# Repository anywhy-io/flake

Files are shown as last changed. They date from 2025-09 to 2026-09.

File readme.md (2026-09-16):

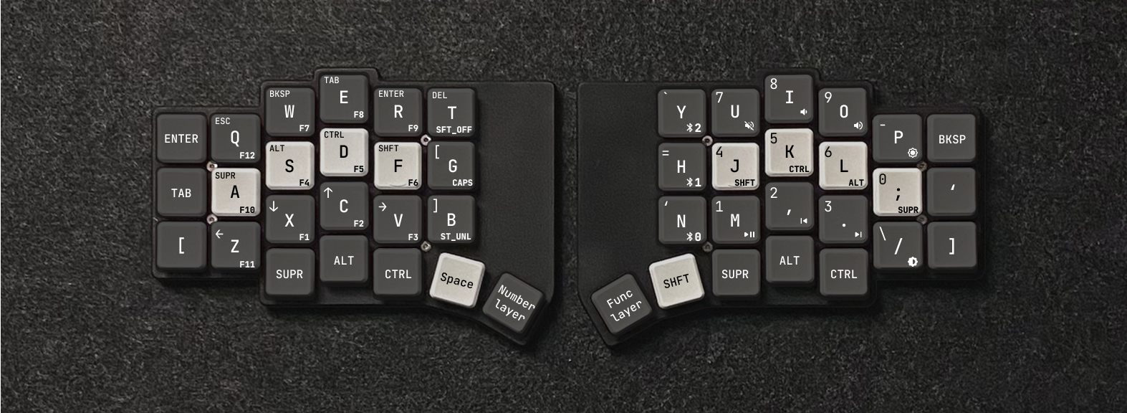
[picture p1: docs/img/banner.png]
Anywhy Flake keyboard


**Anywhy Flake**

_An open, programmable, wireless, ergonomic keyboard_

## Features

- All docs and design files are public. Parts are standard and replaceable.
- Three sizes: S (40 keys), M (46), or L (58).
- Hybrid hot-swap sockets fit low- and high-profile switches: MX, Choc v1, Choc v2, GLP v3.
- Remap any key. Add layers, macros, and combos.
- The case is 9 mm thick, without switches or feet.
- The two halves link over Bluetooth, and your device connects over Bluetooth or USB-C.
- A single charge gives 4 weeks on the main half and 6 months on the secondary.[^battery]

## Documentation

- [Gallery](./docs/gallery.md)
- [Manufacturing Files](./docs/manufacturing_files.md)
- [Build Guide](./docs/build_guide.md)
- [Flashing Guide](https://github.com/anywhy-io/flake-firmware/blob/main/docs/flashing_guide.md)

## License

CERN-OHL-W-2.0. See [LICENSE](./LICENSE).

[^battery]: Assumes 12 hours of continuous use per day, every day.

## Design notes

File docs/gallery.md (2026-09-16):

---
title: Gallery
---

# Anywhy Flake Gallery

Welcome to the gallery, here you will find amazing Flake builds made by people. This page will be constantly expanding, so if you have a build you want to share, feel free to contact me and I'll add it here.

## by [@Constant_Pin_7757](https://www.reddit.com/r/ErgoMechKeyboards/comments/1q6lvwh/comment/ny8om0r/)

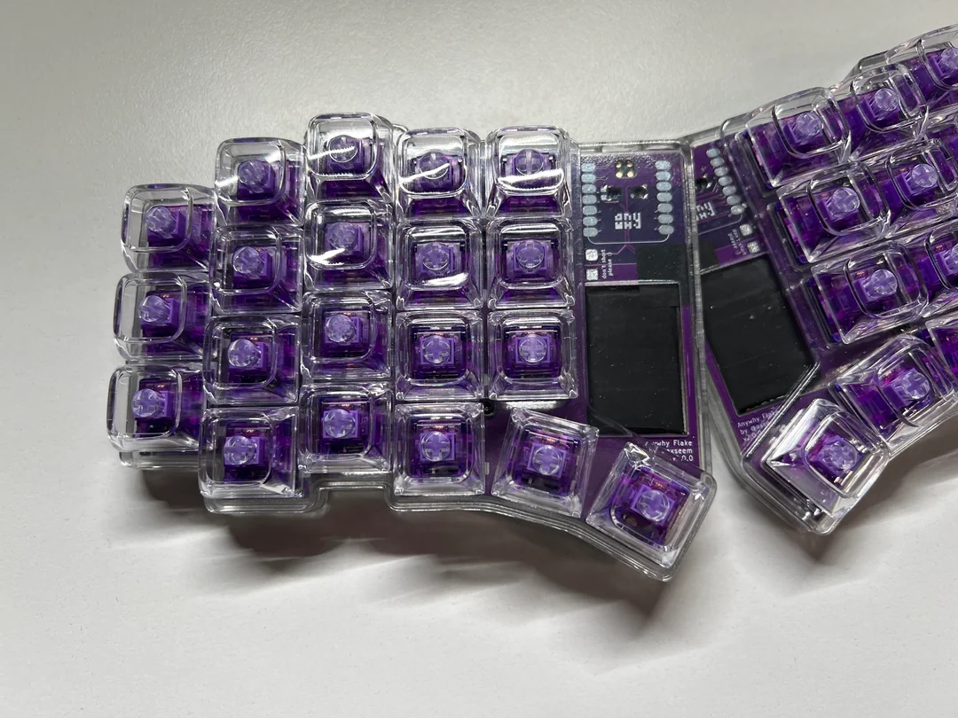
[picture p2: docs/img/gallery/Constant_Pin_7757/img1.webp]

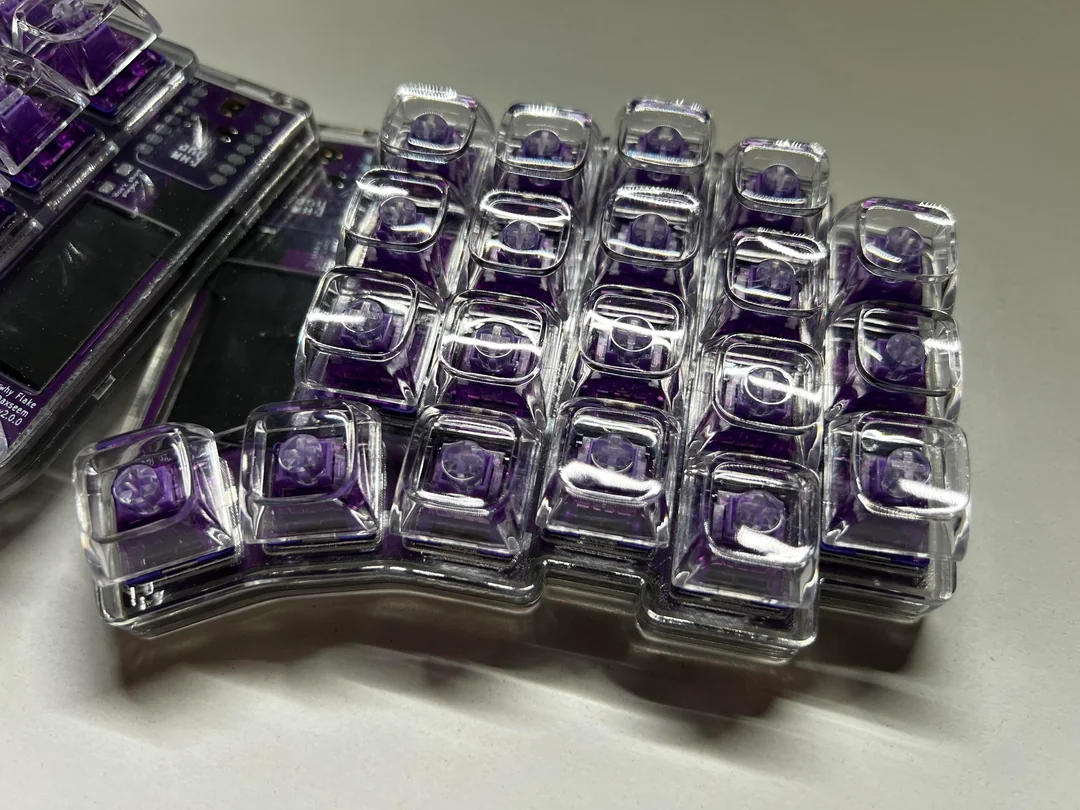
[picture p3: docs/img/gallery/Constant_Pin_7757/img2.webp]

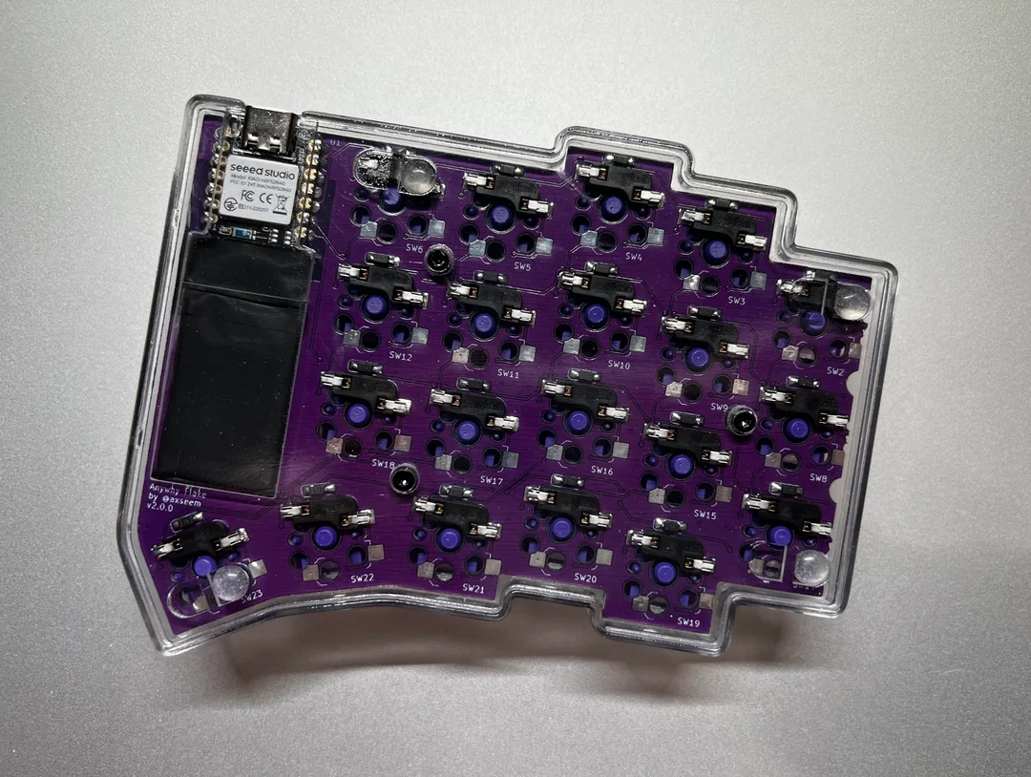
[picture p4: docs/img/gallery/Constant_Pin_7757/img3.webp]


Flake S with transparent housing, lavender PCB and MX switches

## by [@peppapighs](https://www.reddit.com/r/ErgoMechKeyboards/comments/1jbw0kt/my_custom_flake/)

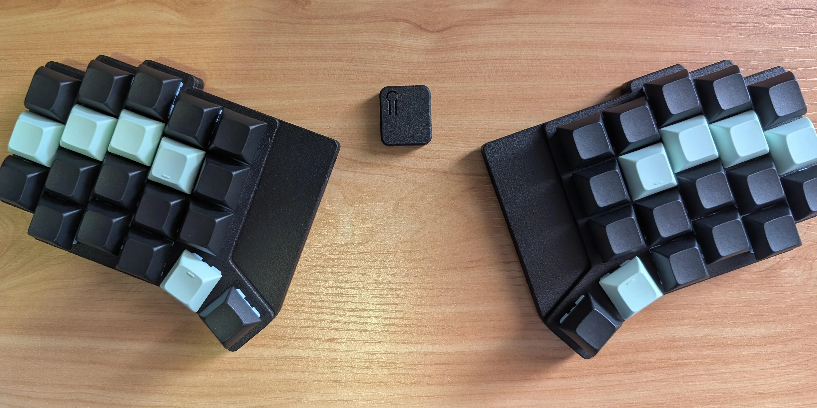
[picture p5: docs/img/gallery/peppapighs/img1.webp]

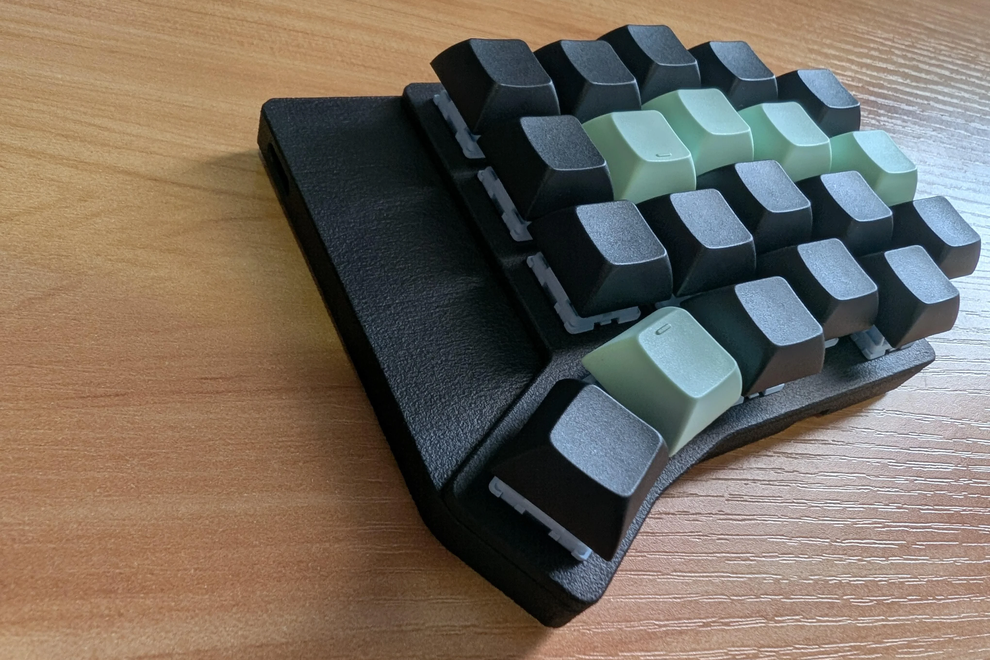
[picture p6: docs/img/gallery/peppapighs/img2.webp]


Flake S with modified PCB adding through-holes for MCU mounting

## by [@caiodelgado](https://www.reddit.com/r/ErgoMechKeyboards/comments/1iz07kw/anywhy_flake_choc_v1_robinsunset_tenting/)

Flake with Choc v1 Robin switches, 3d-printed keycaps and tenting legs

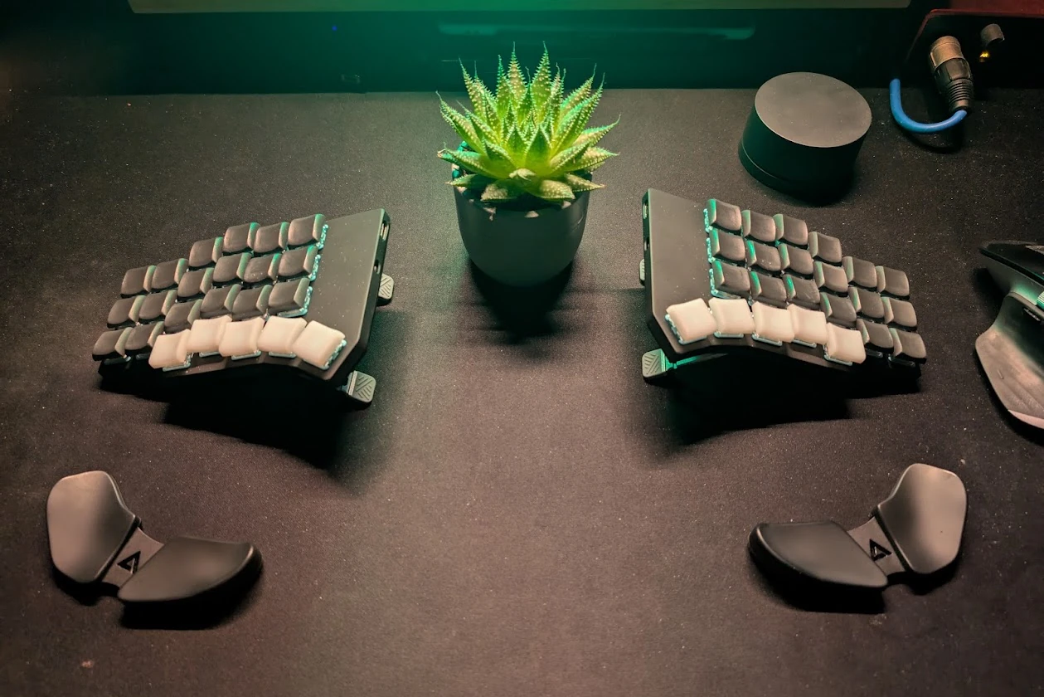
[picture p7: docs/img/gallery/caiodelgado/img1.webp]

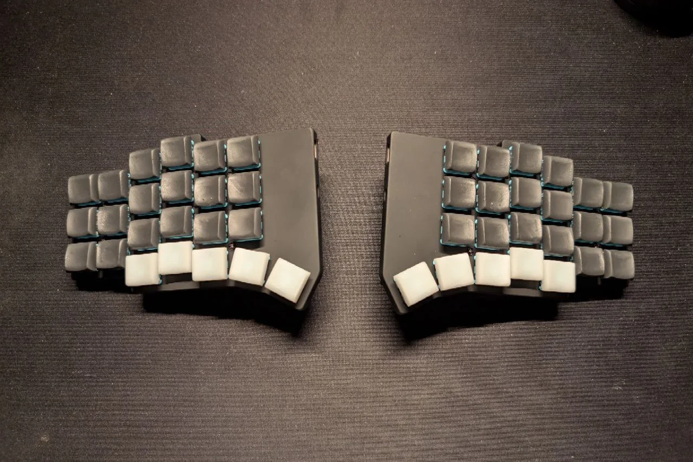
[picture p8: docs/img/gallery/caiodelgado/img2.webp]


## by [@kurisutofujp](https://www.reddit.com/r/ErgoMechKeyboards/comments/1iirgyt/comment/mb9034h/)

Snow-white Flake L with MX switches

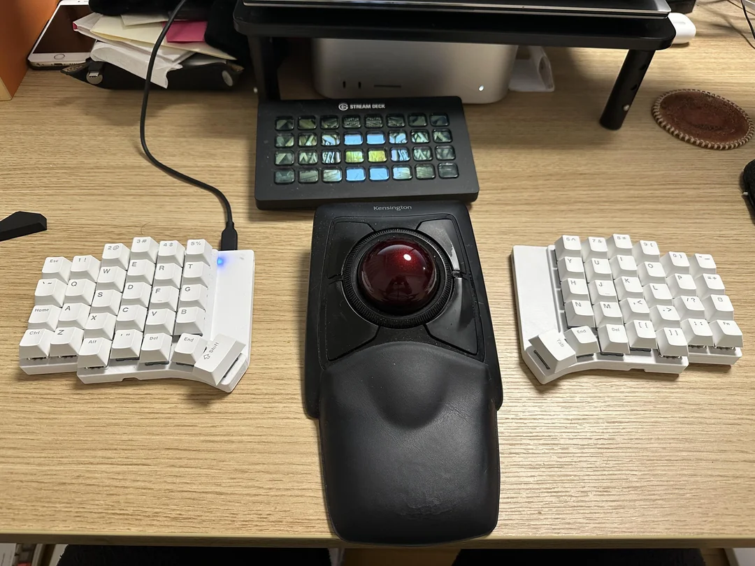
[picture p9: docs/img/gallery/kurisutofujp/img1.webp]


## by [@devpew](https://www.reddit.com/r/ErgoMechKeyboards/comments/1ieevvh/flake/)

Clean white Flake M with black keycaps

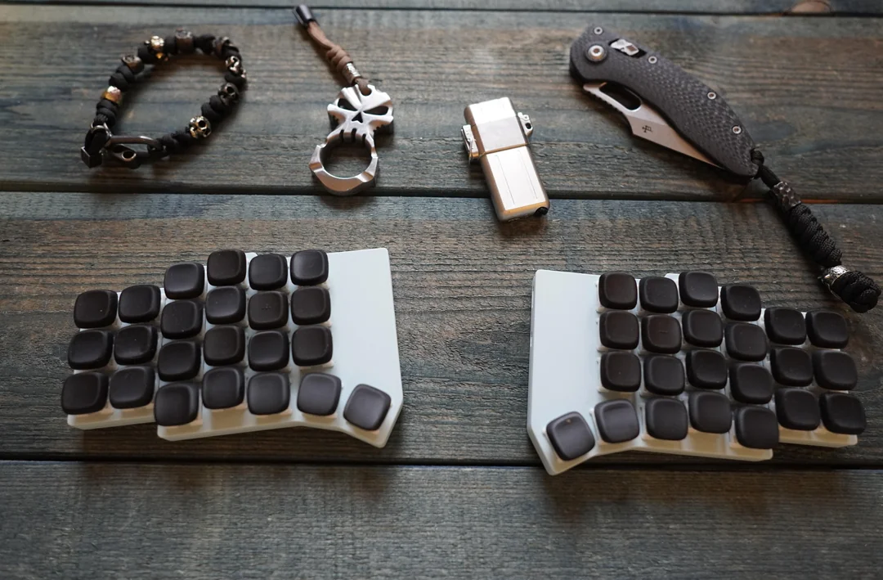
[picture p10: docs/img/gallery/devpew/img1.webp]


## by [@CaptLynx](https://www.reddit.com/r/ErgoMechKeyboards/comments/1ic3nkc/caitlynarcane_themed_anywhy_flake/)

The design is inspired by Caitlyn, a character from the Arcane series.

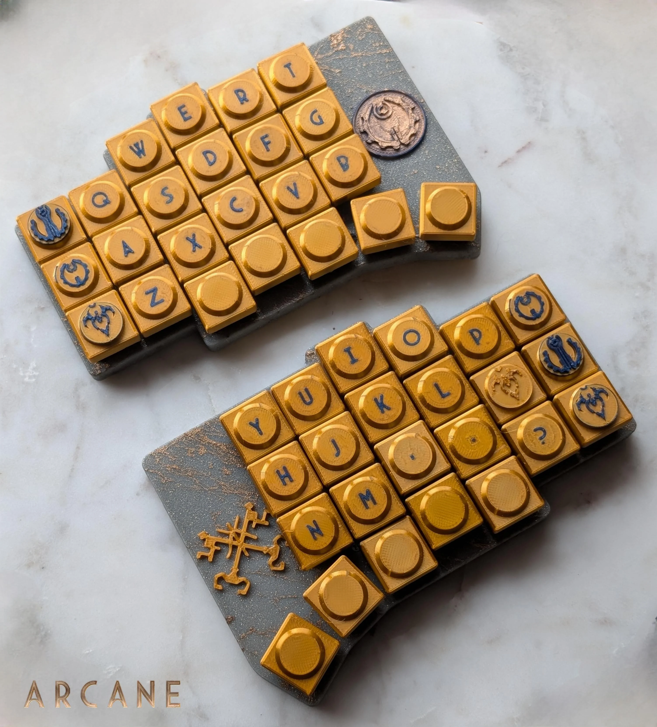
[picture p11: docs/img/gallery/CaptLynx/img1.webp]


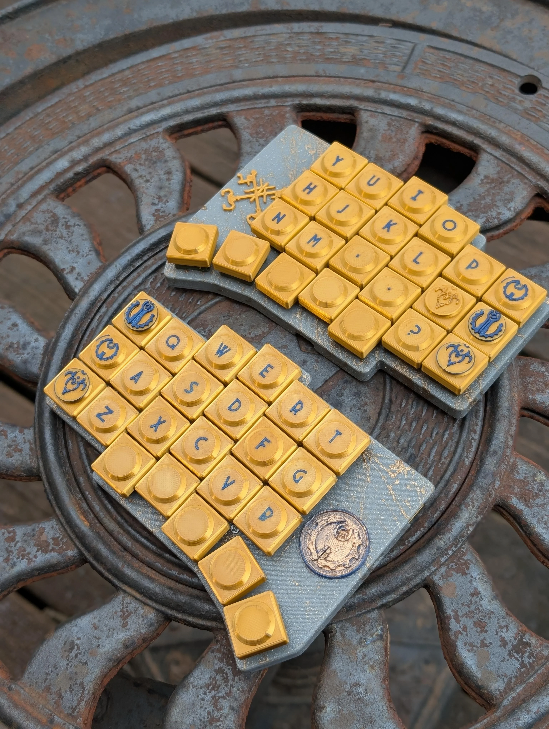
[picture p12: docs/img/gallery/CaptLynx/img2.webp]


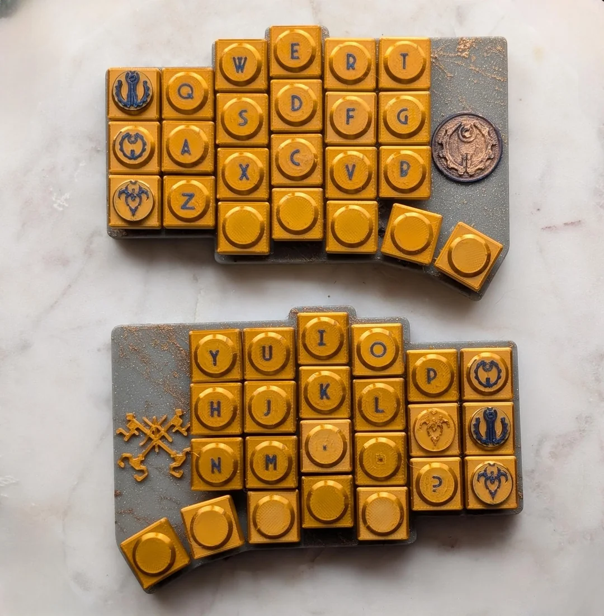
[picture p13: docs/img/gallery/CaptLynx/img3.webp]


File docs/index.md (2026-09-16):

---
title: Flake
---

Flake Keyboard

## Anywhy Flake

*An open-source, wireless, split ergonomic keyboard designed to be productive, healthy, and enjoyable.*

## Why Flake?

By the 19th century, a need for a faster way of writing had emerged, leading to the invention of typewriters. Two centuries later, modern keyboards don't look much different, even though their monolithic, row-staggered design has been proven to be inefficient and often harmful.

The Flake keyboard addresses these problems from the ground up, providing huge benefits in comfort and efficiency for anyone who spends their day typing.

## Core Features

*   **Split Ergonomic Design:** Place each half where it feels best, eliminating wrist strain.
*   **Columnar Stagger:** Keys are arranged to follow the natural movement of your fingers.
*   **Wireless First:** True wireless freedom with Bluetooth LE. At least 4 weeks of battery on the main half and 6 months on the secondary.[^battery]
*   **Hybrid Hot-Swap:** Supports **MX**, **Kailh Choc v1**, **Kailh Choc v2** and **GLP v3** switches.
*   **Three Sizes:** Choose the layout that fits you perfectly: **Small (40)**, **Medium (46)**, or **Large (58)** keys.
*   **Ultra-Thin Profile:** An incredibly sleek and low-profile body for maximum comfort.
*   **Fully Open:** All hardware and software files are published. Standard replaceable parts, no lock-in, no cloud — it's yours to build, modify, and repair.

## The Philosophy Behind the Design

### Split Layout
Regular keyboards force your forearms to converge, bending your wrists at an unnatural angle that can lead to long-term pain. A split keyboard allows you to position each half independently, aligning your hands, wrists, and forearms in a straight, comfortable line. As a bonus, you get free space between the halves for a trackpad, notebook, or even a cat =^..^=

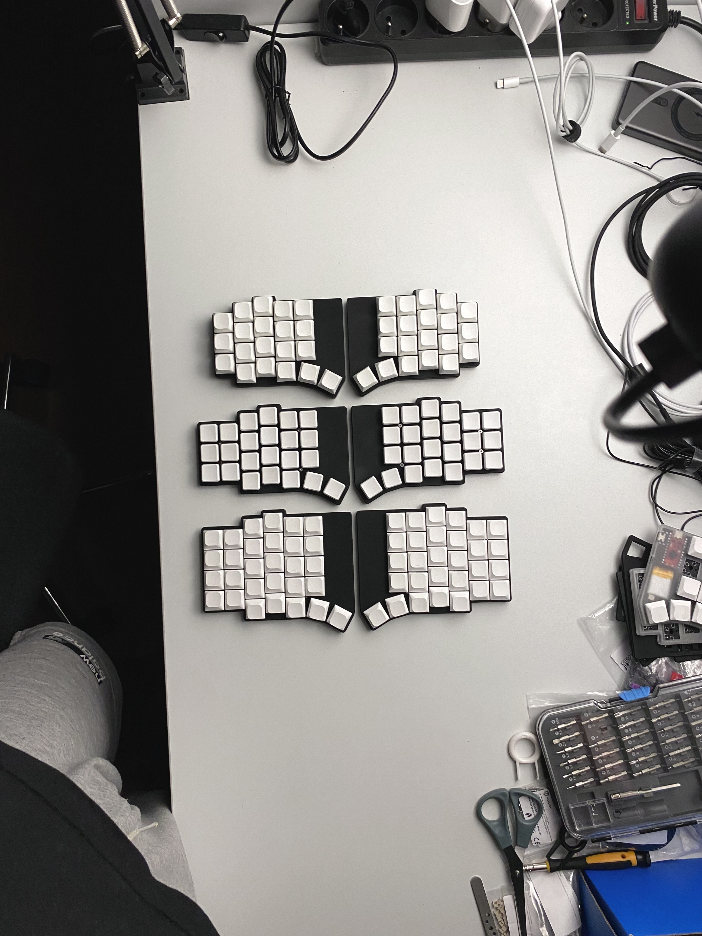
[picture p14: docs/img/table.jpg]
Ergonomic positioning of a split keyboard


### Columnar Stagger
Look at your hand - your fingers have different lengths and prefer to move up and down. Now look at a traditional keyboard - the keys are shifted horizontally. This "row stagger" forces your fingers to make awkward, unnatural movements. Flake uses a "columnar stagger", where each column is shifted vertically to match the natural reach of your fingers, resulting in a much more pleasant and efficient typing experience.

row-based stagger keyboard image

Comparison of row stagger and column stagger

### Hybrid Switch Support
The world of mechanical switches is vast and exciting, but choosing just one type can be limiting. Flake solves this with hybrid hot-swap sockets. Each key position has sockets for both **Cherry MX-style** and **low-profile Kailh Choc** switches. This gives you the freedom to experiment with different switch types at any time.

To provide the best typing feel and stability for the taller MX switches, a dedicated switch plate is included with the case files. This plate is placed over the PCB before inserting the switches, ensuring they are held securely. Low-profile Choc switches mount directly and do not require the plate.

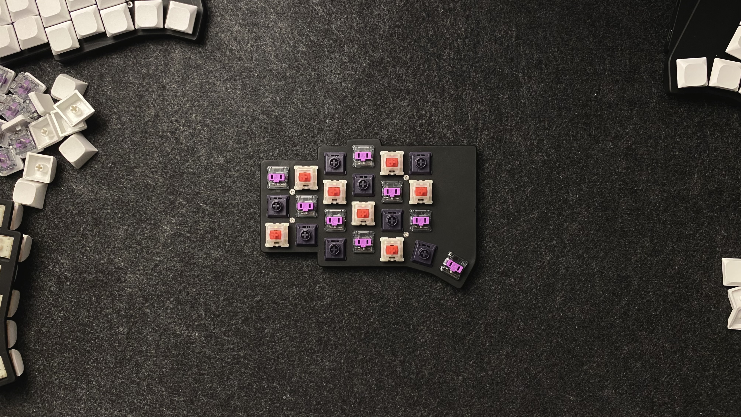
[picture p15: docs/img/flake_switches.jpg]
Flake keyboard showing both MX and Choc switches


### Fewer Keys, More Power
A small key count might seem counterintuitive for productivity, but it's a core feature, not a compromise. Fewer keys mean your hands stay in one place, eliminating the need to stretch for distant keys.

This doesn't mean less functionality. Powered by the incredible [ZMK Firmware](https://zmk.dev), Flake uses [layers](https://zmk.dev/docs/keymaps#layers) to access every key a traditional keyboard has and more. You can have dedicated layers for numbers, symbols, navigation, macros, and anything else you can imagine, all just a thumb press away.

Visual representation of keyboard layers in ZMK

To accommodate different preferences, Flake comes in three sizes:
*   **Flake L (58 keys):** For those who prefer more dedicated keys.
*   **Flake M (46 keys):** A perfect balance of function and form.
*   **Flake S (40 keys):** For the ultimate in minimalism and ergonomics.

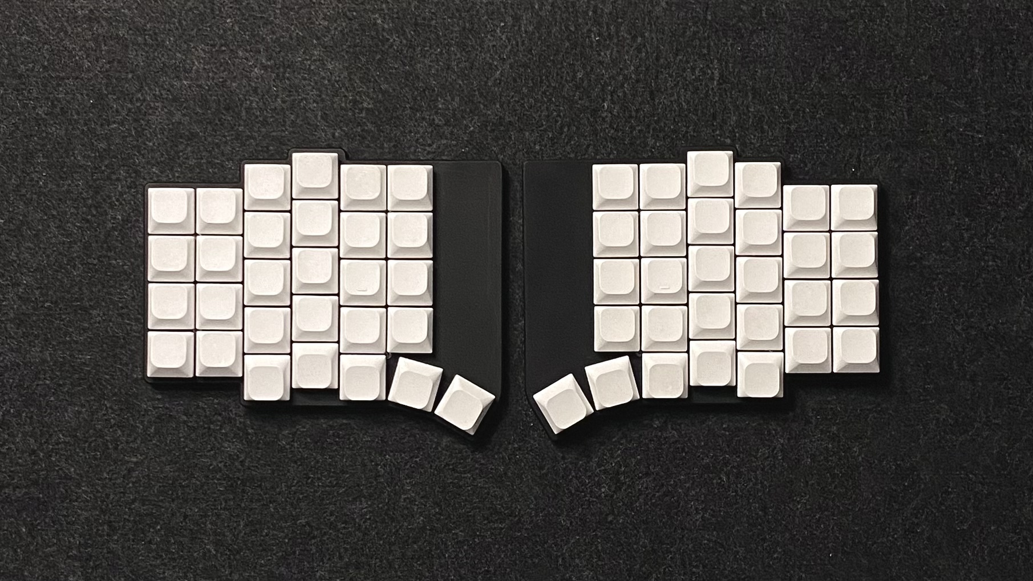
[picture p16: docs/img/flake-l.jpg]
Flake L keyboard


### Ultra-Thin Profile
The keyboard body is only **~9mm** thick (without feet). Combined with low-profile Choc switches and keycaps, this creates an extremely low-to-the-desk typing experience, further reducing wrist strain.

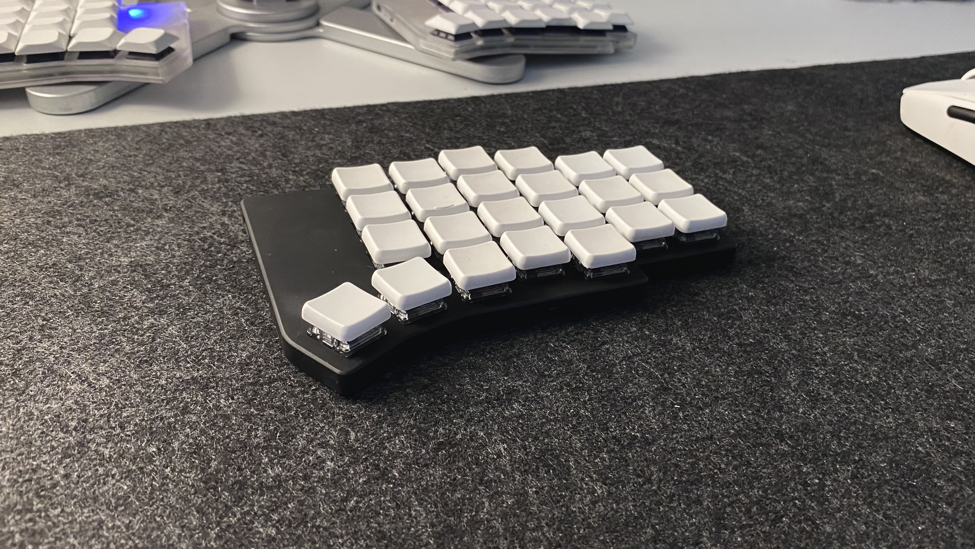
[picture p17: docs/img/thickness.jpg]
Side profile showing the thinness of the Flake keyboard


## Build Your Own Flake

Ready to build one? The comprehensive build guide has everything you need to get started.
➡️ **[Read the Official Build Guide](./build_guide.md)**

Also, be sure to check out the gallery to see amazing builds from the community!
➡️ **[Explore the Gallery ✨](./gallery.md)**

Firmware installation and keymap customization are covered in the firmware documentation.
➡️ **[Flashing Guide](https://github.com/anywhy-io/flake-firmware/blob/main/docs/flashing_guide.md)**

## Credits

Huge thanks to:
-   [@foostan](https://github.com/foostan) for the [Corne Keyboard](https://github.com/foostan/crkbd), my introduction to the world of ergonomic keyboards.
-   [@pashutk](https://github.com/pashutk) for the [Chocofi](https://github.com/pashutk/chocofi), an amazing tiny keyboard I've been using for a while.
-   [@josefadamcik](https://github.com/josefadamcik) for the [Sofle](https://github.com/josefadamcik/SofleKeyboard), which heavily inspired the Flake's key layout.
-   [@carrefinho](https://github.com/carrefinho) for the [Forager](https://github.com/carrefinho/forager). Its clever controller mount allowed v2 to use the Seeed Xiao controller while keeping the keyboard thin.
-   [@ebastler](https://github.com/ebastler/) for his amazing [marbastlib](https://github.com/ebastler/marbastlib), which is used as the basis for the switch footprints.
-   [@petejohanson](https://github.com/petejohanson) and all the [contributors](https://github.com/zmkfirmware/zmk/graphs/contributors) for creating and maintaining the incredible [ZMK Firmware](https://github.com/zmkfirmware/zmk).
-   Everyone working on [KiCad](https://gitlab.com/kicad/code/kicad) and [FreeCAD](https://github.com/FreeCAD/FreeCAD) for creating such powerful open source tools.
-   The helpful and kind people from the [ZMK Discord server](https://zmk.dev/community/discord/invite) who helped me learn PCB design and solve countless problems.
-   Thank you to everyone who explores unpopular technologies, digs into niche topics, and makes amazing things possible.

[^battery]: Assumes 12 hours of continuous use per day, every day.

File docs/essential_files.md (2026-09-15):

---
title: Essential Files
---

# Where is the PCB Gerber file?

You can find these files in their respective directories based on keyboard size:

```
pcb/<keyboard-size>/production/
```

Download the appropriate Gerber files for your keyboard version:

- [Flake S/M](https://github.com/anywhy-io/flake/blob/main/pcb/M%2CS/production/Flake.zip)
- [Flake L](https://github.com/anywhy-io/flake/blob/main/pcb/L/production/Flake-L.zip)
  
# Where are the Enclosure files?

Enclosure files are organized by keyboard size in the following directory structure:

```
enclosure/<keyboard-size>/
```

Select the enclosure files matching your keyboard version:

- [Flake S](https://github.com/anywhy-io/flake/tree/main/enclosure/S)
- [Flake M](https://github.com/anywhy-io/flake/tree/main/enclosure/M)
- [Flake L](https://github.com/anywhy-io/flake/tree/main/enclosure/L)

There you can also find a variant of back plate with cutout for battery connector.

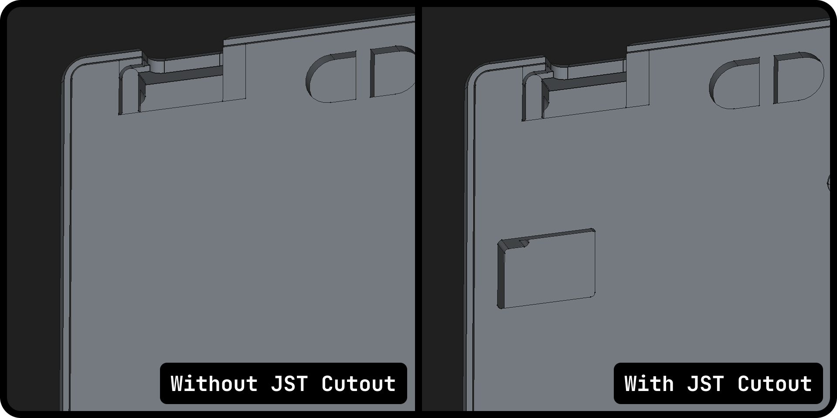
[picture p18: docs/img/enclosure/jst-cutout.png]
ZMK Studio USB connection


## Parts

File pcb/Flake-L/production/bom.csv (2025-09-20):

Designator | Footprint | Quantity | Value | LCSC Part #
BAT+1, BAT-1 | Pad | 2 | Pad
BT1 | JST_1.25mm_Reversible | 1 | Battery
D1, D10, D11, D12, D13, D14, D15, D16, D17, D18, D19, D2, D20, D21, D22, D23, D24, D25, D26, D27, D28, D29, D3, D4, D5, D6, D7, D8, D9 | D_SOD-123_HandSoldering_Reversible | 29 | D
SW1, SW10, SW11, SW12, SW13, SW14, SW15, SW16, SW17, SW18, SW19, SW2, SW20, SW21, SW22, SW23, SW24, SW25, SW26, SW27, SW28, SW29, SW3, SW4, SW5, SW6, SW7, SW8, SW9 | SW_MX_Choc_Hotswap_Reversible | 29 | SW_Push
U1 | XIAO-nRF52840-SMD | 1 | XIAO-nRF52840-SMD

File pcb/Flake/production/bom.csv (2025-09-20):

Designator | Footprint | Quantity | Value | LCSC Part #
_2, |  | 2
BAT+1, BAT-1 | Pad | 2 | Pad
BT1 | JST_1.25mm_Reversible | 1 | Battery
D1, D10, D11, D12, D13, D14, D15, D16, D17, D18, D19, D2, D20, D21, D22, D23, D3, D4, D5, D6, D7, D8, D9 | D_SOD-123_HandSoldering_Reversible | 23 | D
SW1, SW10, SW11, SW12, SW13, SW14, SW15, SW16, SW17, SW18, SW19, SW2, SW20, SW21, SW22, SW23, SW3, SW4, SW5, SW6, SW7, SW8, SW9 | SW_MX_Choc_Hotswap_Reversible | 23 | SW_Push
U1 | XIAO-nRF52840-SMD | 1 | XIAO-nRF52840-SMD

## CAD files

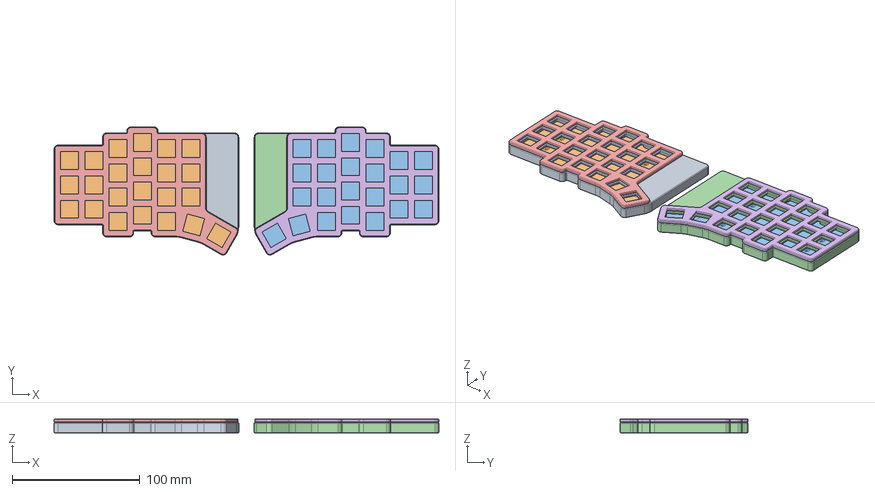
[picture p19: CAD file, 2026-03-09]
enclosure/Enclosure.FCStd
301.4 x 100.4 x 11.3 mm
Top-Left
Bottom-Left001
Bottom-Right001
Top-Right
Plate-Left
Plate-Right

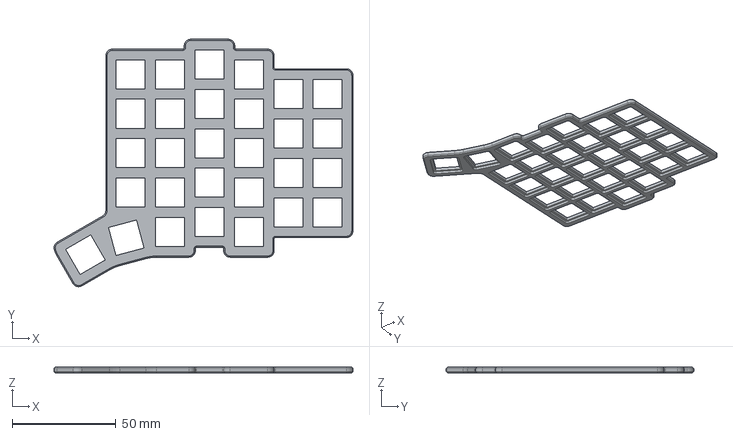
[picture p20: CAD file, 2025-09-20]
enclosure/L/Flake-L-MX-Plate-Right.step
144.2 x 119.4 x 2.80 mm

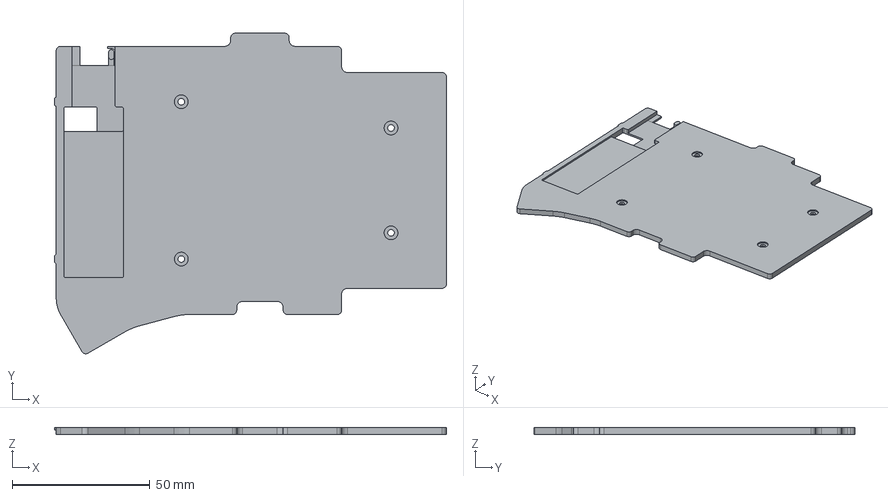
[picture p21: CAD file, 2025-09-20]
enclosure/L/with-jst-cutout/Flake-L-Bottom-Right-JST-Cutout.step
142.1 x 116.2 x 2.60 mm

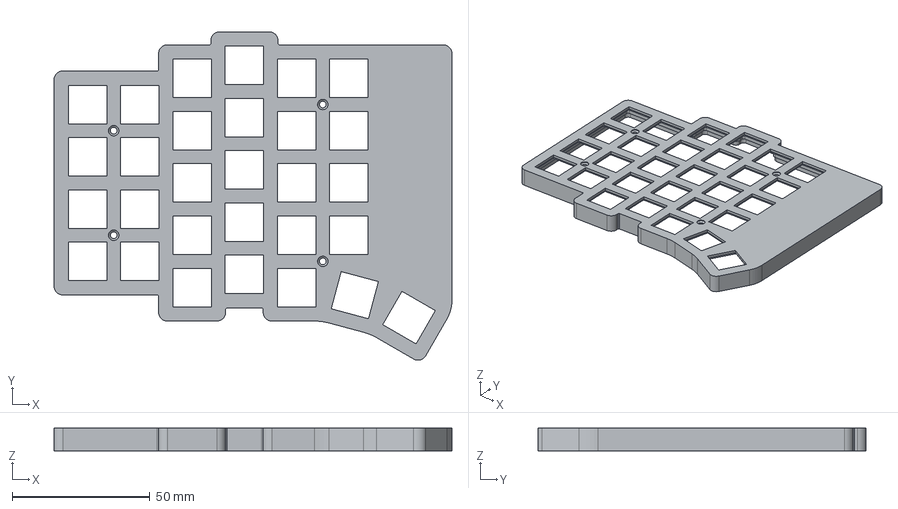
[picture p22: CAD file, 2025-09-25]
enclosure/L/without-chamfer/Flake-L-Top-Left-No-Chamfer.step
144.7 x 119.4 x 8.30 mm

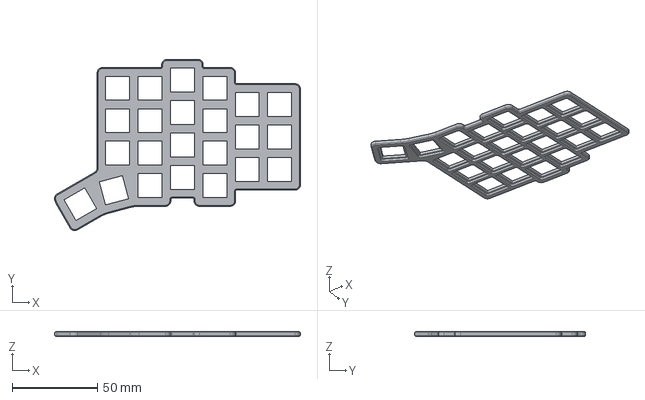
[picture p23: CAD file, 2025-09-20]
enclosure/M/Flake-M-MX-Plate-Right.step
144.2 x 100.4 x 2.80 mm

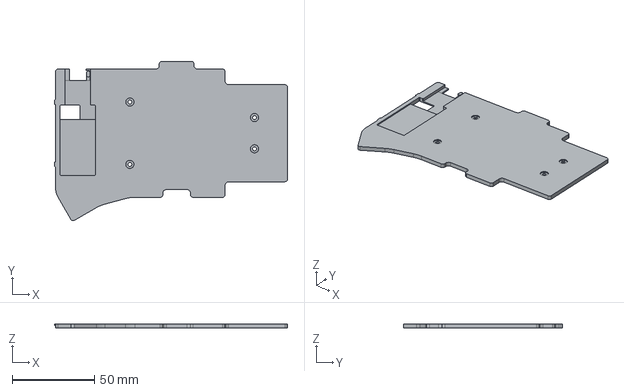
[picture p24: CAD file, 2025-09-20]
enclosure/M/with-jst-cutout/Flake-M-Bottom-Right-JST-Cutout.step
142.1 x 97.2 x 2.60 mm

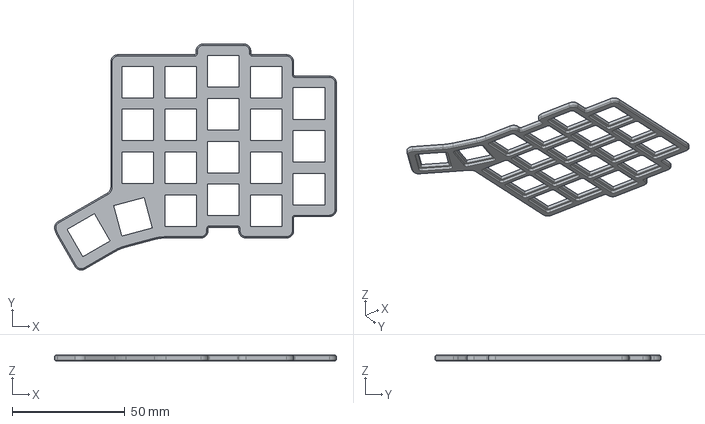
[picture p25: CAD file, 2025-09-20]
enclosure/S/Flake-S-MX-Plate-Right.step
125.2 x 100.4 x 2.80 mm

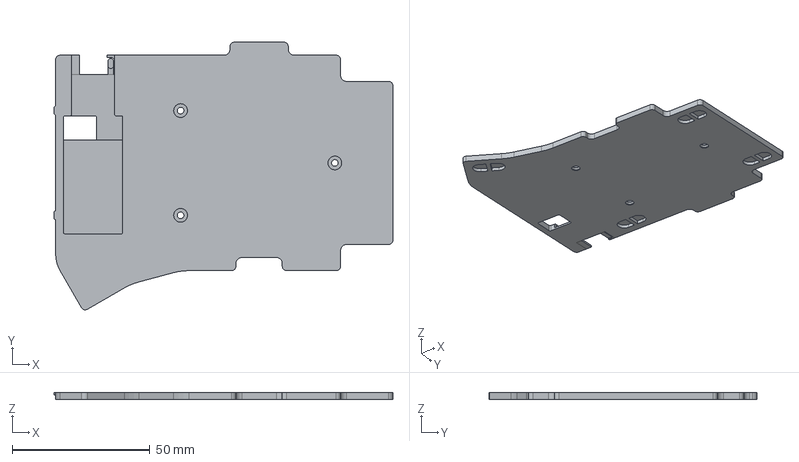
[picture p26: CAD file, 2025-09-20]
enclosure/S/with-jst-cutout/Flake-S-Bottom-Right-JST-Cutout.step
123.1 x 97.2 x 2.60 mm

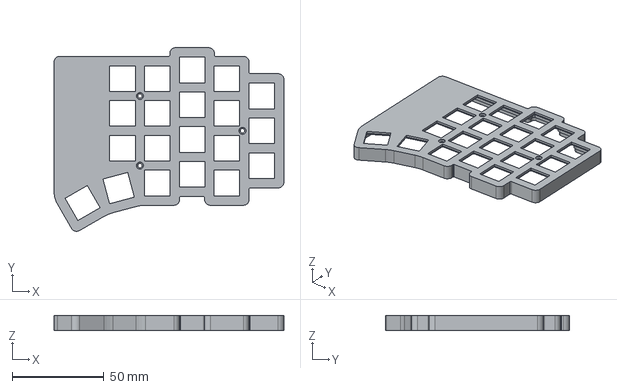
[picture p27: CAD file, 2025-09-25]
enclosure/S/without-chamfer/Flake-S-Top-Right-No-Chamfer.step
125.6 x 100.4 x 8.30 mm

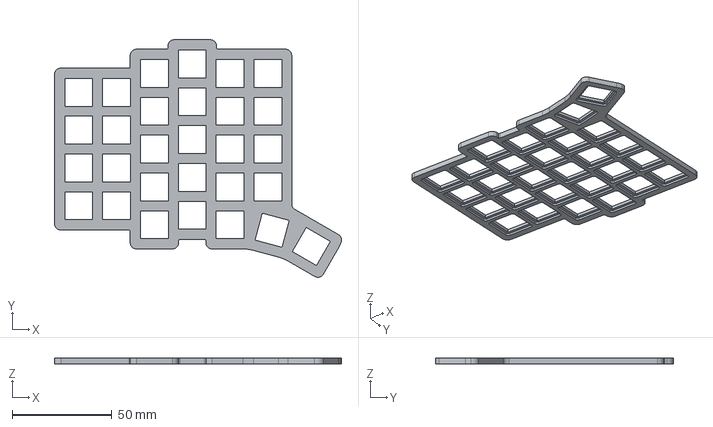
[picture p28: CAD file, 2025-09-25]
enclosure/L/without-chamfer/Flake-L-MX-Plate-Left-No-Chamfer.step
144.2 x 119.4 x 2.80 mm

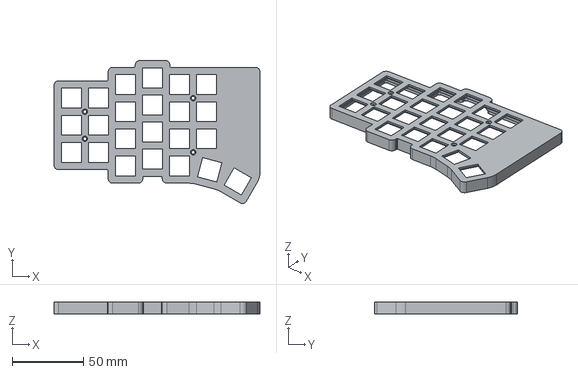
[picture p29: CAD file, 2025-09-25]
enclosure/M/without-chamfer/Flake-M-Top-Left-No-Chamfer.step
144.6 x 100.4 x 8.30 mm

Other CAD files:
enclosure/M/without-chamfer/Flake-M-MX-Plate-Left-No-Chamfer.step
enclosure/L/Flake-L-MX-Plate-Left.step
enclosure/L/with-jst-cutout/Flake-L-Bottom-Left-JST-Cutout.step
enclosure/M/Flake-M-MX-Plate-Left.step
enclosure/M/with-jst-cutout/Flake-M-Bottom-Left-JST-Cutout.step
enclosure/S/Flake-S-MX-Plate-Left.step
enclosure/S/with-jst-cutout/Flake-S-Bottom-Left-JST-Cutout.step
enclosure/L/Flake-L-Bottom-Left.step
enclosure/L/Flake-L-Bottom-Right.step
enclosure/L/Flake-L-Top-Left.step
enclosure/L/Flake-L-Top-Right.step
enclosure/L/without-chamfer/Flake-L-MX-Plate-Right-No-Chamfer.step
enclosure/L/without-chamfer/Flake-L-Top-Right-No-Chamfer.step
enclosure/M/Flake-M-Bottom-Left.step
enclosure/M/Flake-M-Bottom-Right.step
enclosure/M/Flake-M-Top-Left.step
enclosure/M/Flake-M-Top-Right.step
enclosure/M/without-chamfer/Flake-M-MX-Plate-Right-No-Chamfer.step
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

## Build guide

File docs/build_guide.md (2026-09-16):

---
title: Build Guide
---

# Flake Keyboard Build Guide

Welcome to the official build guide for the Flake keyboard! This guide is designed to be comprehensive and easy to follow, even if this is your first time building a keyboard.

I recommend reading through the entire guide once before you begin to familiarize yourself with the process.

## Prerequisites

Before you start soldering or assembling, make sure you have all the necessary components and tools.

### Required Tools

- **Soldering Iron:** A quality soldering iron with adjustable temperature control is essential.
- **Solder:** Lead-free solder is strongly recommended for health and safety.
- **Flux:** A flux pen or paste will make soldering significantly easier.
- **Tweezers:** Essential for handling small components.
- **Screwdriver:** For the M2 screws used in the case.
- **(Optional) Multimeter:** Useful for troubleshooting.

### Required Files

You will need the manufacturing files for the PCB and the enclosure. You can find all the necessary files and instructions on where to order them here:
➡️ **[Manufacturing Files and Ordering Guide](manufacturing_files.md)**

### Bill of Materials (BOM)

The required components vary based on the size of the keyboard you are building. The number of keys for each size is:

- **Small:** 40 keys
- **Medium:** 46 keys
- **Large:** 58 keys

| Component | Small (40) | Medium (46) | Large (58) | Notes |
| :---| :---: | :---: | :---: | :--- |
| **Soldering Components** | | | | |
| Anywhy Flake v2 PCB | 2 | 2 | 2 | One for each half |
| Seeed Xiao nRF52840 | 2 | 2 | 2 | The microcontroller |
| JST 1.25 SMD 2pin Horizontal Connector | 2 | 2 | 2 | For the battery |
| MX Hot-swap Sockets | 40 | 46 | 58 | See note below |
| Choc Hot-swap Sockets | 40 | 46 | 58 | See note below |
| 1N4148 Diodes | 40 | 46 | 58 | 1 per switch (SOD-123 or SOD-323) |
| **Assembly Components** | | | | |
| Soldered PCB | 2 | 2 | 2 | From the step above |
| Switches (Choc v1/v2 or MX) | 40 | 46 | 58 | 1 per socket |
| Keycaps | 40 | 46 | 58 | Must be compatible with your switches |
| Enclosure | 1 set | 1 set | 1 set | Includes top and bottom parts for each half |
| 502030 LiPo Battery (up to 502050 for Flake L) | 2 | 2 | 2 | Or smaller, with a JST 1.25 plug |
| 6x2mm Rubber Feet | 8 | 8 | 8 | |
| M2x4mm Stand-offs | 6 | 8 | 8 | |
| M2x4mm Flat Countersunk Screws | 12 | 16 | 16 | e.g., DIN965 |

> [!NOTE]
> **Sockets:** The Flake PCB supports both MX and Choc switches simultaneously. This guide shows you how to solder both socket types for maximum flexibility. If you are certain you will only ever use one type of switch, you can choose to solder only the corresponding sockets (MX or Choc) and omit the other set.

---

## 1. Soldering the PCB

This is the most detailed part of the build. Take your time, work in a well-ventilated area, and double-check your work as you go. Always use flux, start with a small amount of solder and add more if needed.

### Preparation

#### A. Understand the Reversible PCB

The Flake uses a **reversible PCB**. This means you use the same PCB design for both the left and right halves - you just flip one over. The assembly process is identical for both halves. This guide will walk you through building one half. **Simply repeat all steps on the second PCB, ensuring it is flipped to the opposite side.**

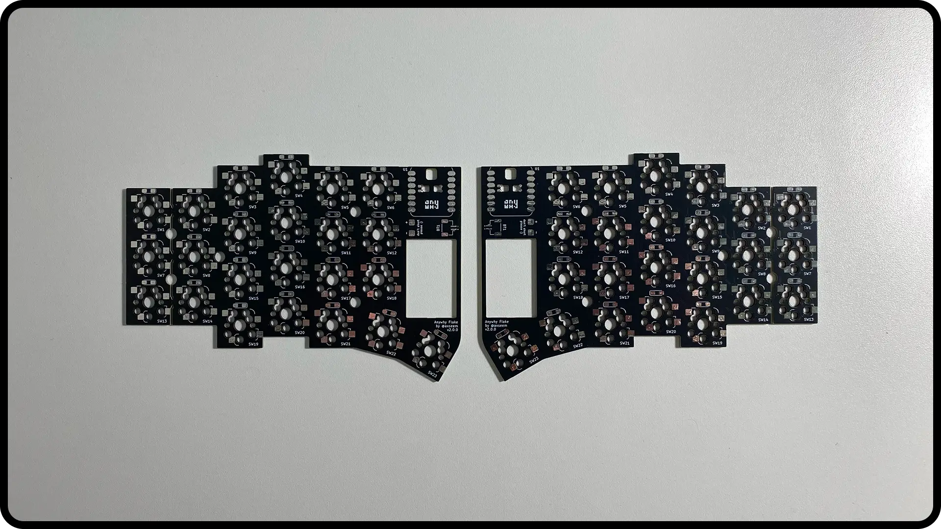
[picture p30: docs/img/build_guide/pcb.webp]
Two reversible Flake PCBs


#### B. Clean the Holes Under the Controller

Due to the manufacturing process, the controller pin holes may be partially obstructed. Before placing the controller, you must carefully clear these obstructions using a tip of your tweezers.

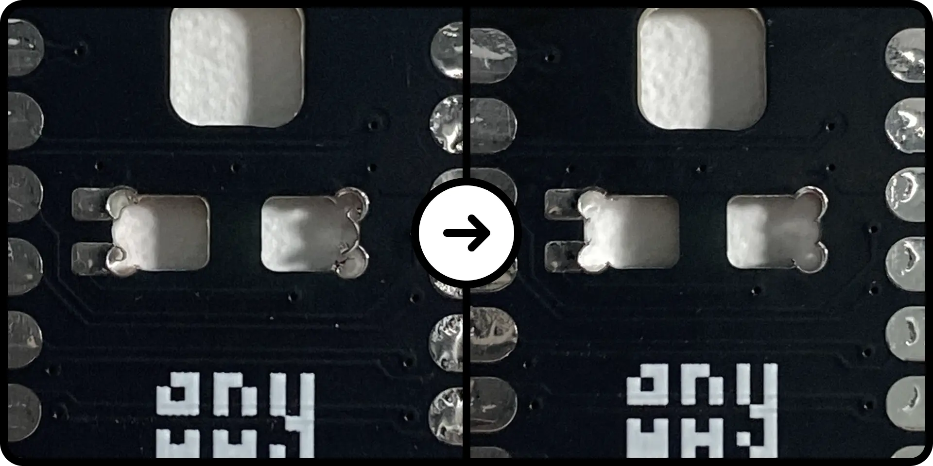
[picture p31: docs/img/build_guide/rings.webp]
Before and after cleaning the controller pin holes


#### C. Break the PCB (Small Version Only)

If you are building the 40-key **Small** version, as I do in this guide, you must snap off the outer pinky column from both PCBs. **If you are building the Medium or Large version, skip this step and leave the PCBs intact.**

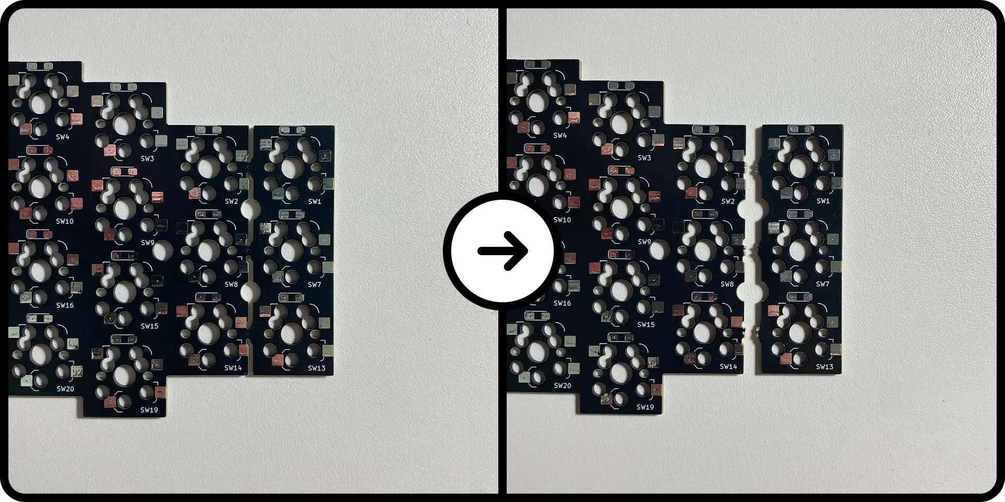
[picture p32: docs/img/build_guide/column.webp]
Breaking off the outer column for the Small version


#### D. Prepare Your Components

Lay out the PCB and the components you will be soldering for one half.

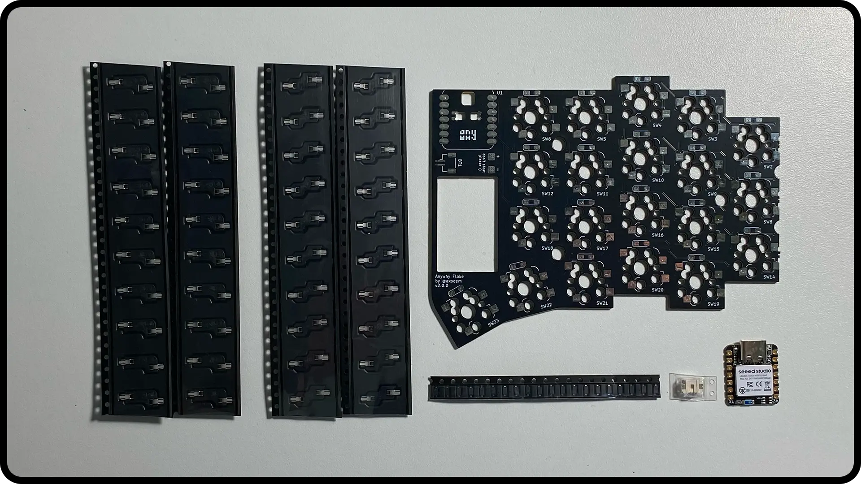
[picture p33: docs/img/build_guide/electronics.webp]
All components for soldering one PCB half


### Step 1: Battery Connector (JST)

> [!TIP]
> If your battery doesn't have a JST plug, you can solder it directly to the `RAW` (+) and `GND` (-) pads next to the JST footprint. However, this is not recommended as it makes the battery difficult to replace later.

1. Place the JST 1.25 connector onto its footprint at position `BT1`.
2. Solder the two large mounting pads to secure connector.
3. Solder the two small pins.

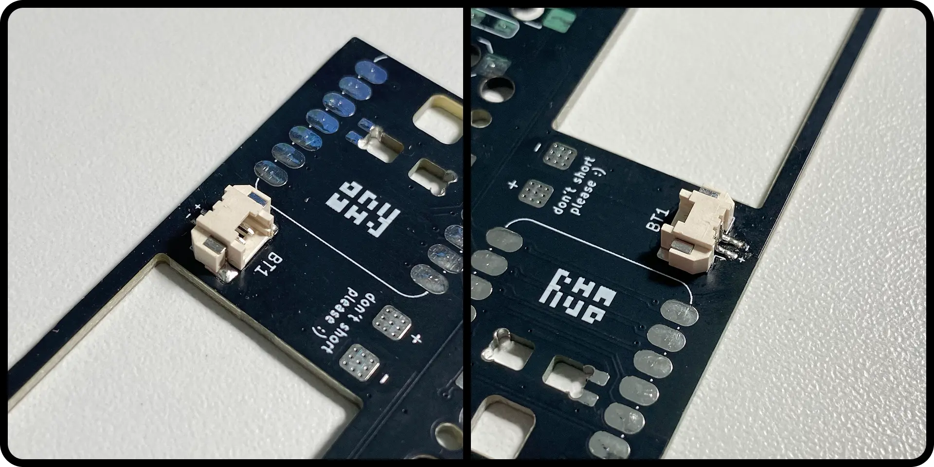
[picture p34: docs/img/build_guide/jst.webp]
Soldering the JST battery connector


### Step 2: Controller (Seeed Xiao)

> [!IMPORTANT]
> Proper alignment is critical. A misaligned controller may prevent the keyboard from fitting into the enclosure.

1. Place the Xiao controller onto its footprint inside the `U1` outline. The USB-C port should face outwards.
2. Solder **one corner pin** to tack the controller in place.
3. Check the alignment. If it's crooked, re-heat the pin and adjust.
4. Once aligned, solder the **diagonally opposite corner pin** to lock it in place.

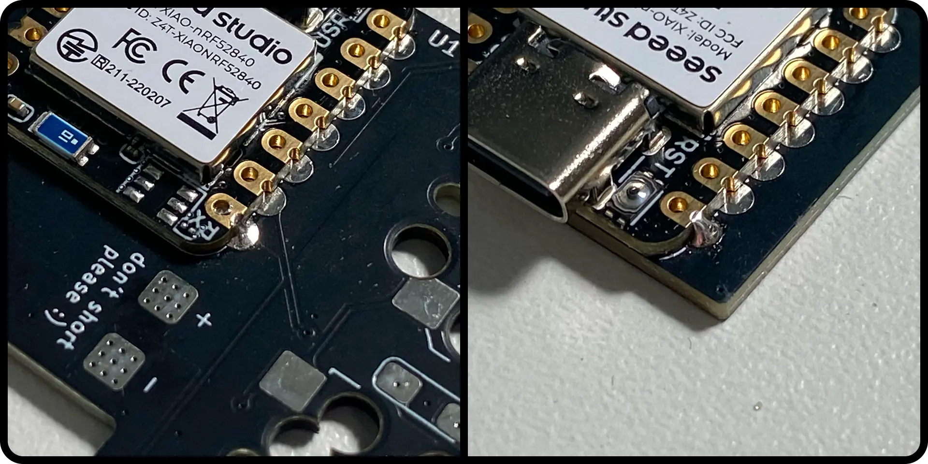
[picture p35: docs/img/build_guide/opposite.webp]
Tacking opposite corner pins of the controller first


5. Proceed to solder all remaining pins.

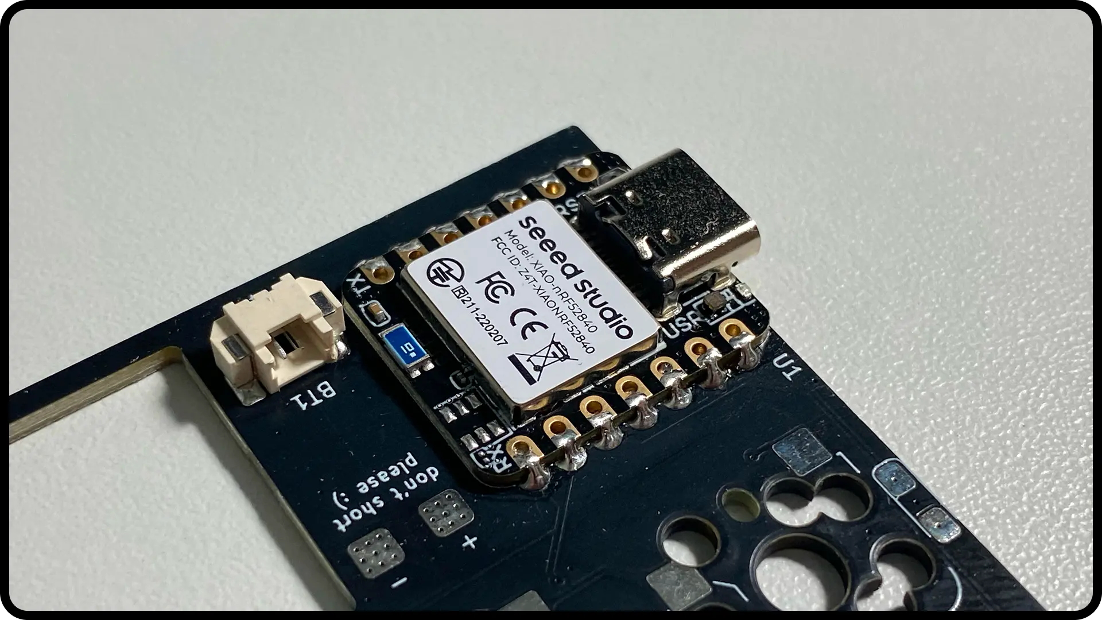
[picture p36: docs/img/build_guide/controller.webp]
All controller pins soldered


6. Flip the PCB and solder the `RAW` and `GND` pads under the controller.

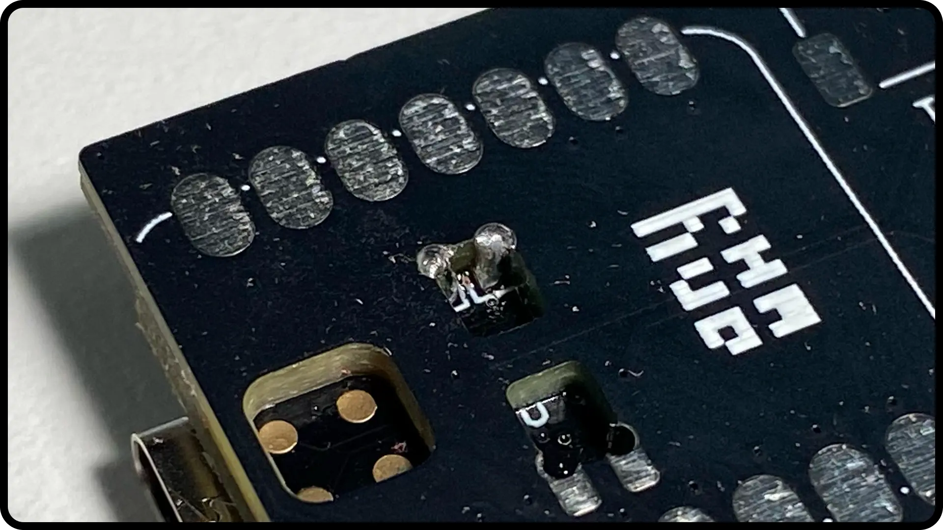
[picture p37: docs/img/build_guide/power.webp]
Soldering the RAW and GND pads under the controller


### Step 3: Diodes

> [!WARNING]
> Diodes are directional! The line on the diode must match the line on the PCB silkscreen. An incorrectly oriented diode will cause that key to fail.

For each switch position:

1. Add a small amount of solder to one of the two diode pads.
2. Using tweezers, slide a diode into place, re-heating the solder blob to secure one side. **Ensure the line on the diode aligns with the line on the PCB outline.**
3. Solder the other leg of the diode.

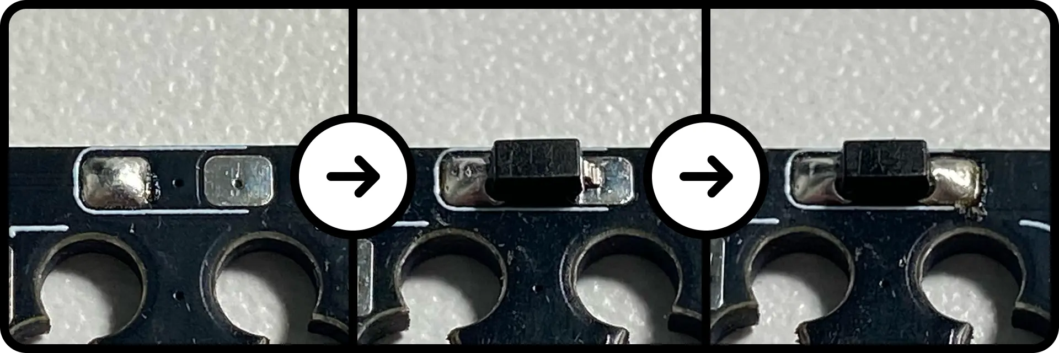
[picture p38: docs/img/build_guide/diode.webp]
Three-step process for soldering a diode


#### Optional: Check the operational functionality

1. Flash the **left** firmware as per [Flashing Guide](https://github.com/anywhy-io/flake-firmware/blob/main/docs/flashing_guide.md) on **both** keyboard Controllers
2. Connect one keyboard half via USB-C to your host
3. Use Via either in [browser](https://www.usevia.app/) or install the [app](https://github.com/cebby2420/via-desktop)
4. Start Via, select your keyboard, go to the keyboard tester and use some solder wire or tweezers to bridge each socket's pad. You should hear a sound and see that the respective key was pressed in the keyboard tester UI. If both halves work, you can continue with the next steps and should not run into any bigger issues, as you just tested that all Diodes work as well as all connection to the Controller

### Step 4: Hot-swap Sockets

For each switch position:

1. Place the **MX socket** in the top position and the **Choc socket** in the bottom position.
2. Solder both metal legs on each socket.

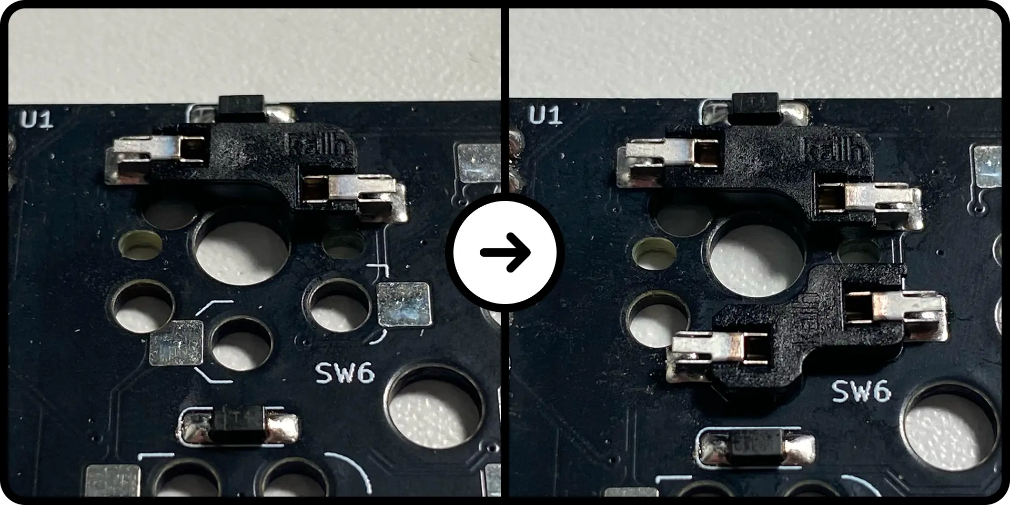
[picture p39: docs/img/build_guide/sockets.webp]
Soldering MX and Choc hot-swap sockets


### Soldering Complete

Congratulations! You have a fully soldered PCB. Take a moment to inspect all your solder joints.

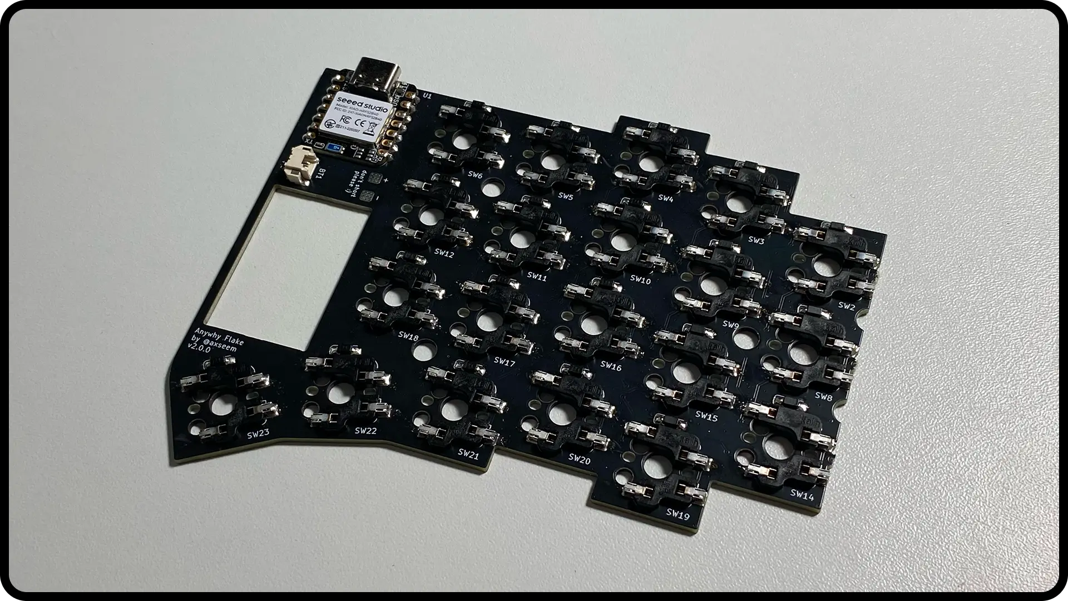
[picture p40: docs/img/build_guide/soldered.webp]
Completed PCB with all components soldered


Now, repeat the entire soldering process for the second PCB. Remember to work on the **opposite side** of the PCB so it becomes a **mirror image** of the first half.

## 2. Case Assembly

With both PCBs soldered, it's time to put everything into the enclosure.

1. Gather the soldered PCB, case parts, battery, standoffs, and screws.

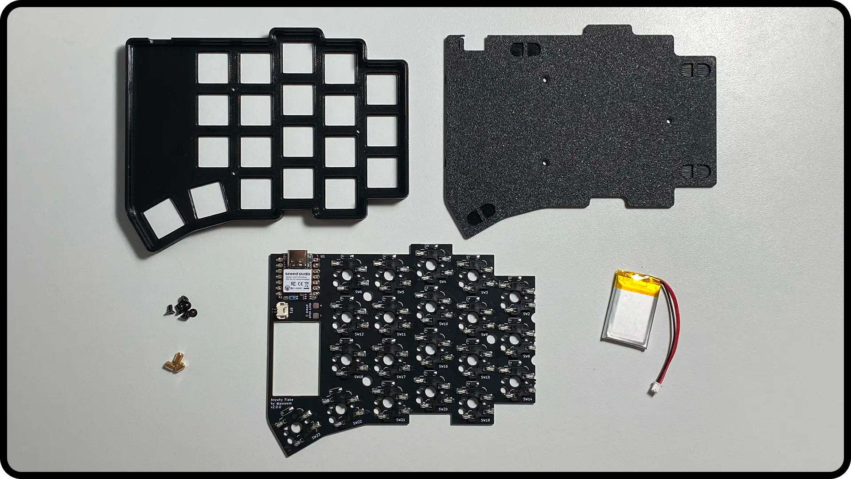
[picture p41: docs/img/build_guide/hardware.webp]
All components for final assembly


2. Screw the M2x4mm standoffs into the **bottom half** of the case.

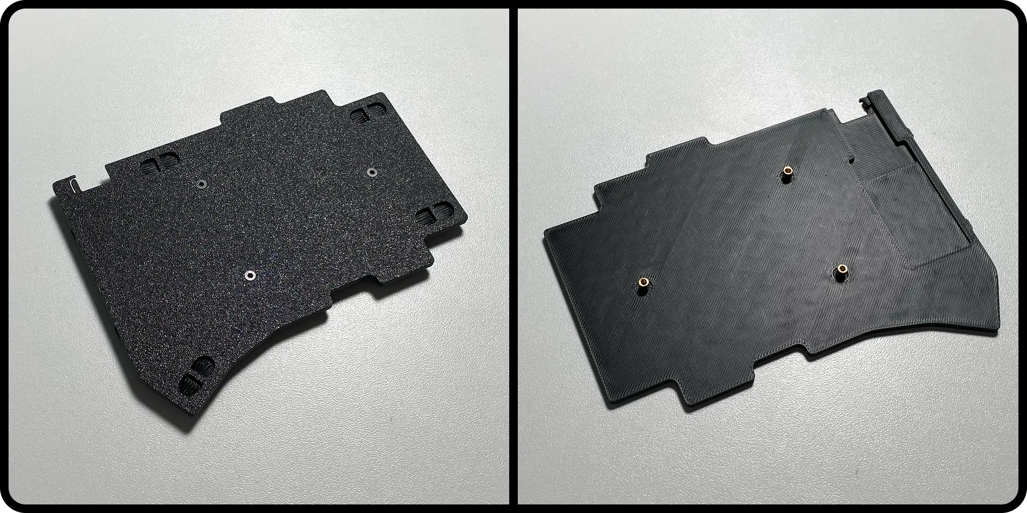
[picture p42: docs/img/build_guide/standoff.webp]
Standoffs installed in the bottom plate


3. Seat the soldered PCB into the **top half** of the case. Connect the battery's JST plug and place the battery into its dedicated cutout.

> [!WARNING]
> **Battery Safety:** Triple-check the polarity before connecting battery. Connecting the battery backwards (red wire to `GND (-)`, black wire to `RAW (+)`) will destroy the microcontroller.

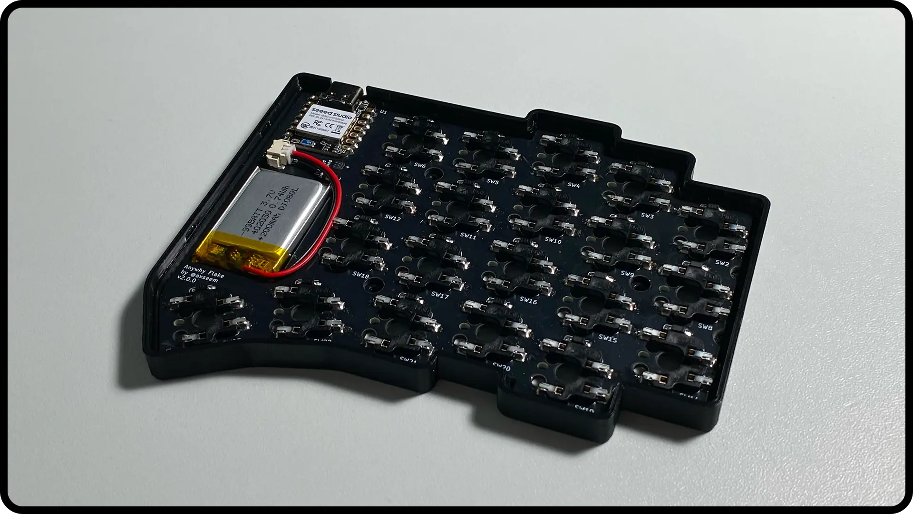
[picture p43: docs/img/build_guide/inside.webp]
PCB and battery placed in the top case


4. Carefully place the bottom plate onto the top part, aligning the standoff holes. Stick the self-adhesive rubber feet onto the dedicated spots on the bottom of the case.

> [!TIP]
> For the second half, place the feet on the opposite corners. This allows the two halves to sit flush against each other back-to-back for transport.

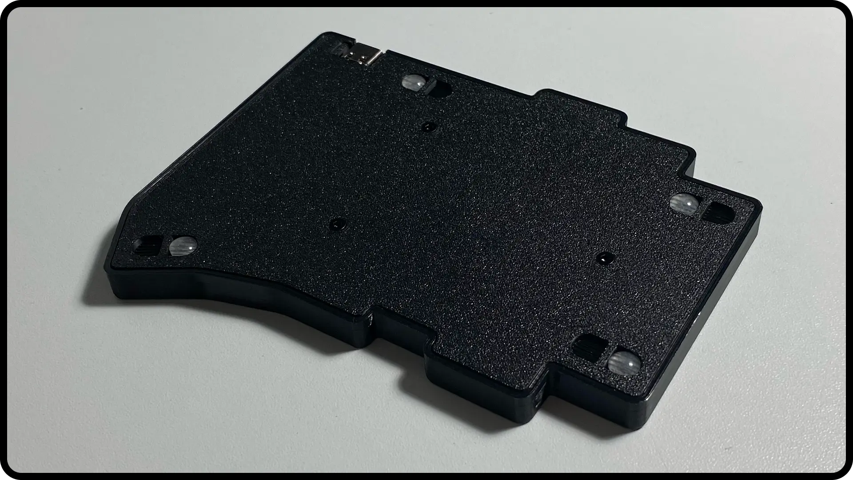
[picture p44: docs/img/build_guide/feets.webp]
Assembled case from the bottom with rubber feet


5. Insert the M2x4mm screws from the top and tighten them. Do not overtighten.

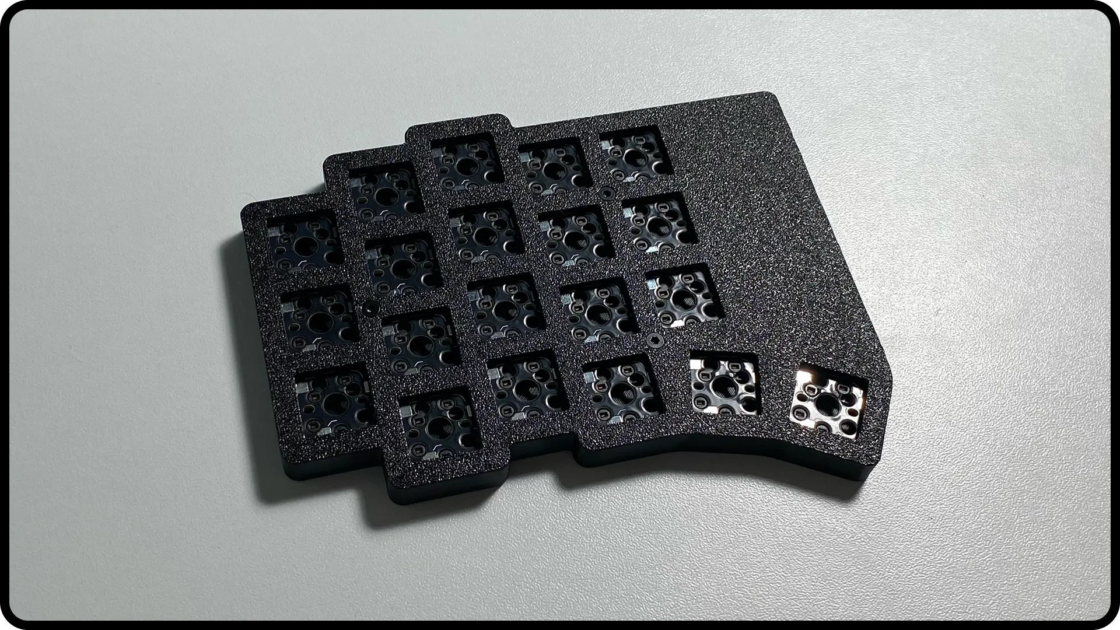
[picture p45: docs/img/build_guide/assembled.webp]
Screws installed from the top to secure the case


**Repeat** this assembly process for the second half of the keyboard.

## 3. Final Assembly

> [!IMPORTANT]
> If you are using MX switches, you must place the included MX plate onto the keyboard _before_ inserting the switches.

1. **Insert Switches:** Gently press your chosen switches (MX or Choc) into the corresponding hot-swap sockets. Ensure the switch pins are straight to avoid bending them.

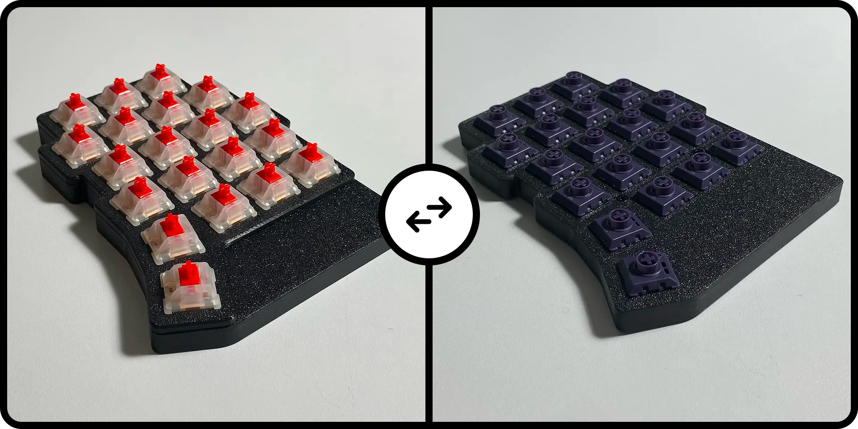
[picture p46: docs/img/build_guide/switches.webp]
Inserting either MX or Choc switches


2. **Install Keycaps:** Press your keycaps firmly onto the switch stems.

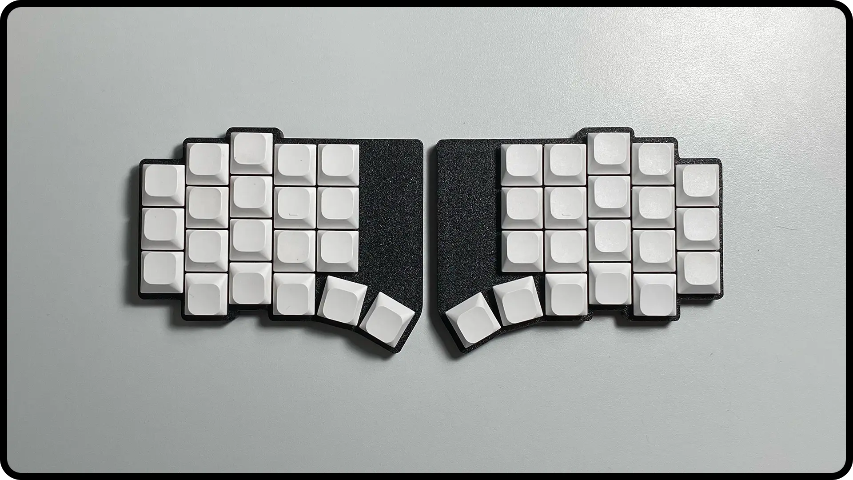
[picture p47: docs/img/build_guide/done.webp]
Fully assembled Flake keyboard


## You're Done

Congratulations on building your Flake keyboard! Your keyboard is now physically complete.

The final step is to flash the firmware to make it fully functional. Please proceed to the next guide:
➡️ **[Flashing Guide](https://github.com/anywhy-io/flake-firmware/blob/main/docs/flashing_guide.md)**

## Troubleshooting

1. Check all your solder joints again. Use flux, maybe a lot of flux. It will help creating nice solder joints.
2. Measure all diodes using a multimeter, maybe one was destroyed by too much heat during the solder process. They should all face the same direction (check the PCB again) and pass the test using the multimeter.
3. If you think one key is non-functional: Use a multimeter, press the faulty key or bridge it using a tweezer or a cable, measure respective Pins on the microcontroller for continuity. Use the kicad schema to know which row/col maps to which pins.
4. If you are in doubt, that you killed your Controller, build the testing firmware, flash it to the Controller and test each pin + ground using e.g. some solder wire. In a text editor you should see pin after pin once you bridge them with ground. For more details check the [documentation](https://zmk.dev/docs/troubleshooting/hardware-issues#identifying-issues)

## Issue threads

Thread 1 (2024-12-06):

RP2040 support

devpew, 2024-12-06:
Is it possible to use RP2040 instead of pro micro?
As I can see you solder controller right to plate, but pr2040 a little bit longer than pro micro
Will it works or the controller won't fit into the case after that?

axseem, 2024-12-07:
RP2040 is a chip, and Pro Micro is a board. Footprint of the Pro Micro has become popular for other boards that have various hardware. If your board has a Pro Micro compatible footprint and a mid-mount USB-C port, it should work just fine.

Here is an example of the Pro Micro compatible controller with the RP2040 chip
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

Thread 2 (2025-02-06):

Trouble printing enclosure.

alxzh, 2025-02-06:
I tried to order the enclosure printing from JLC3DP using the step file for the FlakeS but they declined the print saying "Multiple parts are detected in your file, sorry to tell you that each file could only support 1 part for printing, please kindly split the multiple parts into single files to upload separately." I know that you printed this enclosure with them.

Could you please expand the instructions to describe how that step file should be printed or split it into separate files?

alxzh, 2025-02-06:
Here is how I created the request for printing with them.

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

axseem, 2025-02-06:
> I know that you printed this enclosure with them.

The enclosures used to be stored in separate files, but it was a hassle to upload them each time, so I merged them into one file. The JLC3DP website accepted the file with no problem, although I didn't order the enclosure that way. I had no idea that could be a problem.

I will split the enclosure into individual files to address it.

alxzh, 2025-02-06:
Thanks!

alxzh, 2025-02-06:
Looks like there is an issue with the files (corruption?) FreeCad cannot open them and the JLC complains that they are corrupted.

alxzh, 2025-02-06:
That is bizarre now it works. I basically cloned the repo and uploaded files from local copy. The only difference is the I restarted the browser since the last attempt. Sorry for the false alarm.

Closed 2025-02-06.

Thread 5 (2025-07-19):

How to use Bluetooth funtion

Thundercatzzz, 2025-07-19:
I need help with connecting the keyboard with bluetooth

axseem, 2025-07-20:
The repository has a [guide](https://github.com/anywhy-io/flake/blob/main/docs/flashing_guide.md) for the firmware, once completed, the keyboard is ready to connect. Just open the Bluetooth settings on your device and you'll see “Anywhy Flake” in the list of nearby devices. Tap on it to connect. The device will then ask for a 6-digit password to securely connect to the keyboard. Enter them on the Flake keyboard and press Enter (all keys, including Enter, are entered on Flake).

Hope this helps

axseem, 2025-07-20:
What exactly is not working for you? Could you please describe your actions step by step with the result you are getting?

Thundercatzzz, 2025-07-20:
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
To clarify, I'm unable to connect the keyboard via Bluetooth.
I turned on the device and tried to pair it with my computer.
After entering the password, the connection still doesn’t go through.
However, when I use a wired connection, everything works normally.

axseem, 2025-07-20:
So, I guess the most likely problem could be an incorrect password entry. Just in case, I'd like to point out that the numbers are on the number layer, and an image of the key map can be found [here](https://github.com/anywhy-io/flake-zmk-module/#readme).

If that's not the issue, I would also suspect Windows bluetooth drivers. Could you try connecting the Flake to another device (like a phone)?

Thundercatzzz, 2025-07-20:
First of all, thank you for your support!
After I reset all the settings in ZMK, I was finally able to connect the device via Bluetooth.
I'm currently finishing up the case, and once it's done, I'll send you some photos!

Closed 2025-07-20.

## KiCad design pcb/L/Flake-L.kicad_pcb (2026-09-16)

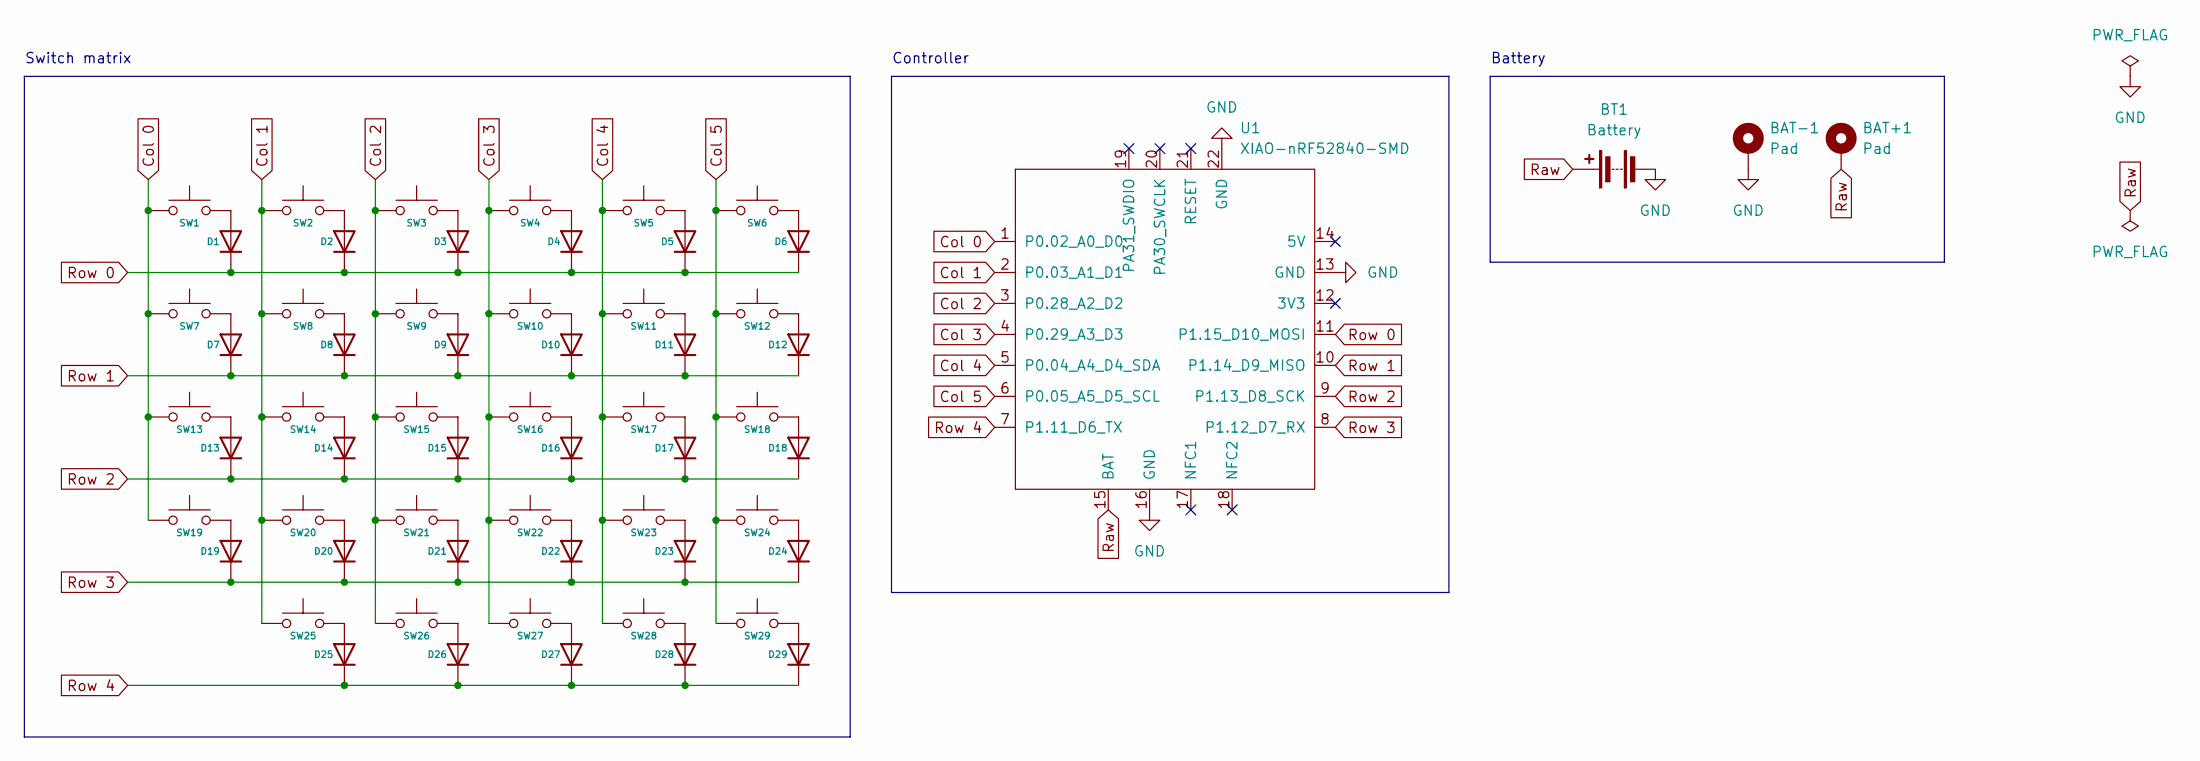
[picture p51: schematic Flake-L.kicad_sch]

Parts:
BAT+1: Pad
BAT-1: Pad
BT1: Battery; JST_1.25mm_Reversible
D1, D2, D3, D4, D5, D6, D7, D8, D9, D10, D11, D12, D13, D14, D15, D16, D17, D18, D19, D20, D21, D22, D23, D24, D25, D26, D27, D28, D29: D; D_SOD-123_HandSoldering_Reversible
SW1, SW2, SW3, SW4, SW5, SW6, SW7, SW8, SW9, SW10, SW11, SW12, SW13, SW14, SW15, SW16, SW17, SW18, SW19, SW20, SW21, SW22, SW23, SW24, SW25, SW26, SW27, SW28, SW29: SW_Push; SW_MX_Choc_Hotswap_Reversible
U1: XIAO-nRF52840-SMD

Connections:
Col 0: SW1.1, SW7.1, SW13.1, SW19.1, U1.1 (P0.02_A0_D0)
Col 1: SW2.1, SW8.1, SW14.1, SW20.1, SW25.1, U1.2 (P0.03_A1_D1)
Col 2: SW3.1, SW9.1, SW15.1, SW21.1, SW26.1, U1.3 (P0.28_A2_D2)
Col 3: SW4.1, SW10.1, SW16.1, SW22.1, SW27.1, U1.4 (P0.29_A3_D3)
Col 4: SW5.1, SW11.1, SW17.1, SW23.1, SW28.1, U1.5 (P0.04_A4_D4_SDA)
Col 5: SW6.1, SW12.1, SW18.1, SW24.1, SW29.1, U1.6 (P0.05_A5_D5_SCL)
GND: BAT-1.1, BT1.2 (-), U1.13 (GND), U1.16 (GND), U1.22 (GND)
unnamed: D1.2 (A), SW1.2
unnamed: D2.2 (A), SW2.2
unnamed: D3.2 (A), SW3.2
unnamed: D4.2 (A), SW4.2
unnamed: D5.2 (A), SW5.2
unnamed: D6.2 (A), SW6.2
unnamed: D7.2 (A), SW7.2
unnamed: D8.2 (A), SW8.2
unnamed: D9.2 (A), SW9.2
unnamed: D10.2 (A), SW10.2
unnamed: D11.2 (A), SW11.2
unnamed: D12.2 (A), SW12.2
unnamed: D13.2 (A), SW13.2
unnamed: D14.2 (A), SW14.2
unnamed: D15.2 (A), SW15.2
unnamed: D16.2 (A), SW16.2
unnamed: D17.2 (A), SW17.2
unnamed: D18.2 (A), SW18.2
unnamed: D19.2 (A), SW19.2
unnamed: D20.2 (A), SW20.2
unnamed: D21.2 (A), SW21.2
unnamed: D22.2 (A), SW22.2
unnamed: D23.2 (A), SW23.2
unnamed: D24.2 (A), SW24.2
unnamed: D25.2 (A), SW25.2
unnamed: D26.2 (A), SW26.2
unnamed: D27.2 (A), SW27.2
unnamed: D28.2 (A), SW28.2
unnamed: D29.2 (A), SW29.2
Raw: BAT+1.1, BT1.1 (+), U1.15 (BAT)
Row 0: D1.1 (K), D2.1 (K), D3.1 (K), D4.1 (K), D5.1 (K), D6.1 (K), U1.11 (P1.15_D10_MOSI)
Row 1: D7.1 (K), D8.1 (K), D9.1 (K), D10.1 (K), D11.1 (K), D12.1 (K), U1.10 (P1.14_D9_MISO)
Row 2: D13.1 (K), D14.1 (K), D15.1 (K), D16.1 (K), D17.1 (K), D18.1 (K), U1.9 (P1.13_D8_SCK)
Row 3: D19.1 (K), D20.1 (K), D21.1 (K), D22.1 (K), D23.1 (K), D24.1 (K), U1.8 (P1.12_D7_RX)
Row 4: D25.1 (K), D26.1 (K), D27.1 (K), D28.1 (K), D29.1 (K), U1.7 (P1.11_D6_TX)

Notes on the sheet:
Switch matrix
Controller
Battery

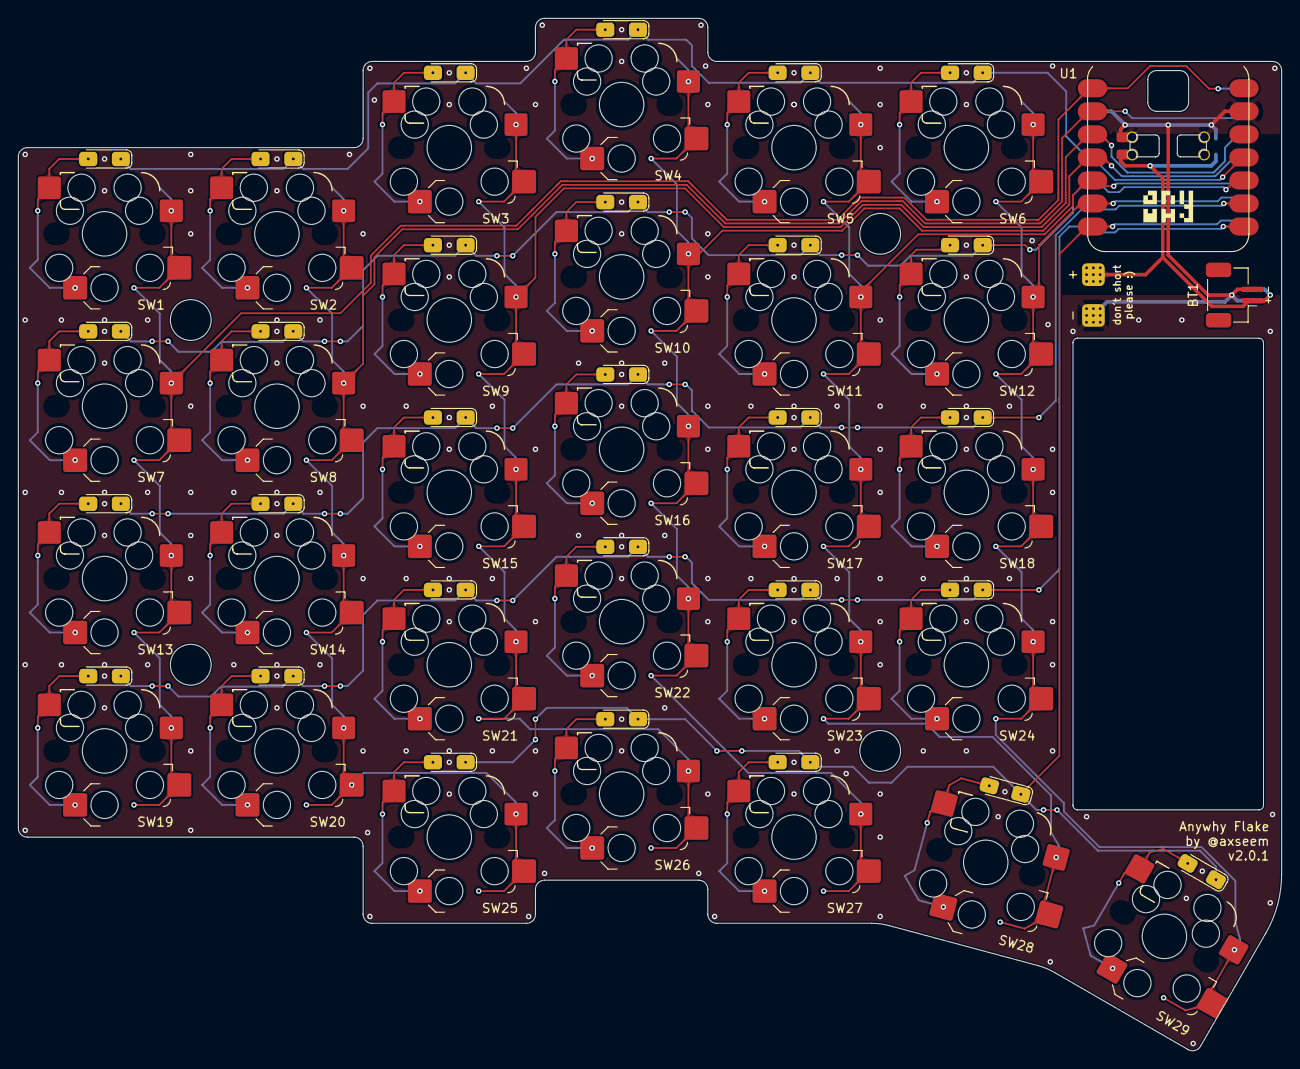
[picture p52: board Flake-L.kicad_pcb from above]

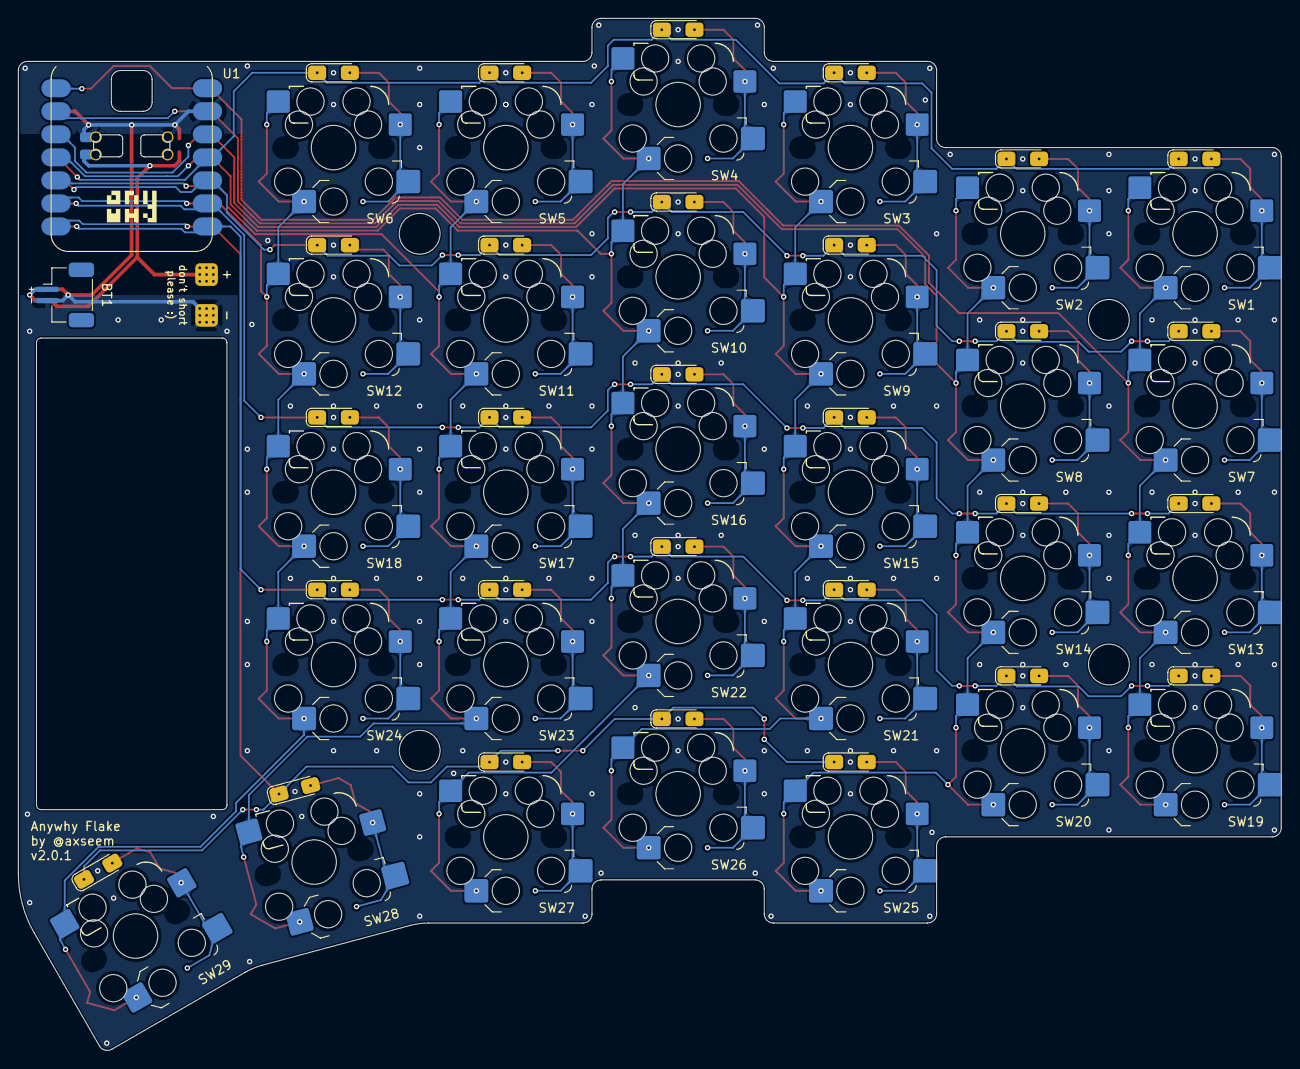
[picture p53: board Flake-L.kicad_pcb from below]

Board: 2 copper layers, 139.2 x 113.8 mm, 62 parts (33 on the bottom side), 42 nets.

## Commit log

2025-01-11 pcb: remove unused footprints
2025-01-13 enclosure: plates: remove surface above controller
    [Enclosure-L-Bottom-Mirrored.step, Enclosure-L-Bottom.step, Enclosure-L-Plate-Mirrored.step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]
2025-01-13 enclosure: fix topology
    [Enclosure-L.FCStd, Enclosure-L.step, Enclosure-M.FCStd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]
2025-02-06 enclosure: split into individual files
    [Enclosure-L-Bottom-Left.step, Enclosure-L-Bottom-Right.step, Enclosure-L-Plate-Left.step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]
2025-09-20 Flake v2
    [Enclosure-L-Bottom-Left.step, Enclosure-L-Bottom-Right.step, Enclosure-L-Plate-Left.step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]
2025-09-20 chore: fix PCB path
    [Flake-L.kicad_sch, Flake.kicad_pcb, Flake.kicad_sch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]
2025-09-25 fix(enclosure): path typo
    [Flake-M-Bottom-Left-JST-Cutout.step, Flake-M-Bottom-Right-JST-Cutout.step]
2025-09-25 feat(enclosure): no chamfer version for easier print
    [Flake-L-MX-Plate-Left-No-Chamfer.step, Flake-L-MX-Plate-Right-No-Chamfer.step, Flake-L-Top-Left-No-Chamfer.step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]
2025-10-15 docs: Flake L supports 502050 battery
2025-10-17 fix(build_guide): screws are 4mm long
2025-11-02 fix(build_guide): update screw size from M2x8mm to M2x4mm in the instructions
2026-03-09 fix: top enclosure resize breaks the model (#17)
    [Enclosure.FCStd]
2026-09-15 docs: add docs landing and move firmware content out
    Add docs/index.md as the documentation landing page, add front matter to the published guides, and remove the language switcher and the Chinese/Russian translations. The flashing guide and its images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
2026-09-16 chore: remove executable bit from non-script files
    Git only tracks the executable bit; these files were committed as 100755 accidentally. Only file modes change here.
    [Flake-L.kicad_pcb, Flake-L.kicad_sch, Flake.kicad_pcb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]
2026-09-16 chore: drop obsolete v2 blend source file
    [anywhy-flake-v2.blend]
2026-09-16 chore: ignore production backups and KiCad local history
2026-09-16 fix(pcb): v2.0.1 boards with 1mm corner cuts and M,S reroute
    [Flake-L.kicad_pcb, Flake.kicad_pcb]
2026-09-16 chore(pcb): refresh fabrication outputs and tool settings
